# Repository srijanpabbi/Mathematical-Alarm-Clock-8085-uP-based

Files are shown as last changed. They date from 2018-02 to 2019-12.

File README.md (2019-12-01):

# Mathematical-Alarm-Clock
#[Find PDF in git repo(Brief Document)]
This device aims to make turning off an alarm a slightly more involving task, forcing the user to focus on the device for some time hence breaking the sleep. It will keep track of time using a RTC and will sound an alarm on the preset time and throw a randomly generated integer based mathematical problem at the user(+,-,/,*), the alarm will stop ringing as soon as the user enters the correct answer to the question. This projects will incorporate a display, a keypad, alarm sounding system(buzzer), and a RTC.

## NETAJI SUBHAS INSTITUTE OFTECHNOLOGY

## DIVISION OFELECTRONICS AND COMMUNICATIONENGINEERING

### EC316 MICROPROCESSORLABPROJECTREPORT

# Mathematical Alarm Clock

## ANINTEL8085 MICROPROCESSOR BASED PROJECT

### Submitted by

### Prabhat Gupta (124EC15)

### Srijan Pabbi (173EC15)

### Submitted to

### Prof. Dhananjay V. Gadre

### May, 2018

## Contents

- 1 Abstract
- 2 Background And Motivation
- 3 Justification
- 4 Block Diagram
- 5 Technical Details
   - 5.1 Hardware
      - 5.1.1 Core Microprocessor (Intel 80C85)
      - 5.1.2 Peripherals And Addressing
      - 5.1.3 RTC(Real Time Clock)
      - 5.1.4 20x4 Character LCD
      - 5.1.5 Key-Pad
      - 5.1.6 Buzzer
   - 5.2 Software Implementation and Interesting Concepts
      - 5.2.1 Big Font and LCD Posting Techniques
      - 5.2.2 Key-Pad Scanning
      - 5.2.3 LFSR(Linear Feedback Shift Register) Implementation
      - 5.2.4 User Setup Inputs With Interrupts
      - 5.2.5 Arithmetic Random Problem Generation With Result Check
- 6 Supporting Materials
   - 6.1 Support Links and References
   - 6.2 Project Schematic And Boards
   - 6.3 Bill of Materials

## 1 Abstract

Everyone must have seen the ordinary alarm clocks that sound only when it is set to be alarmed.Why not
to make a normal alarm period an interesting task. It’s time to get rid of the conventional alarm clocks.
Here what comes the mathematical alarm clock. The mathematical alarm clock is a device that modifies
a conventional alarm clock to a more advanced version that not only alarms but it also makes sure that
the user gets out of sleep for solving some mathematical problems.This device aims to make turning on an
alarm a slightly more involving task. It keeps the trackof time and displays it on the lcd. It does so by using
an RTC (parallel data bus). The Alarm can be set using a keypad. At the time of alarm, a buzzer sounds. The
buzzing of the alarm continues as long as the user would not give the correct answers of certain number of
mathematical problems. At the alarm preset time, the device throws a randomly generated integer based
mathematical problem based on simple arithmetic (+). The alarm stops only after the correct answer is
given by the user. The project incorporates a display (LCD 20x4),keypad, buzzer as an alarming system,
parallel bus RTC

## 2 Background And Motivation

EC-311/316 has provided us an opportunity to build this project under the able guidance of Prof Dhanan-
jay Gadre. The idea of this project is to learn and portray the skill of designing a microprocessor based
system and putting whatever we learn in this course into a useful application. This device aims to make
turning on an alarm a slightly more involving task, forcing the user to focus on the device for some time
hence successfully breaking the sleep as compared to normal alarm clocks. Making this project will involve
almost all the steps required for making a embedded system product namely; planning, designing, getting
the pcb fabricated, coding, and a making an enclosure for the final display, and most importantly docu-
menting throughout the process of making it, which will give us experience on how to design a embedded
product from zero to finish.

## 3 Justification

Mathematical Alarm Clock involves the use of a RTC(Real Time Clock) for time keeping, 20x4 character
LCD for display of time and the generated math questions, and a user input keypad, these devices cannot
be used with simple digital logic devices to perform the job we want out of this project. This project must
be able to display time and, perform background mathematical calculations , accept and compare user
inputs to the answers of the questions which it generated randomly. The need to do all this for successful
working of the project the use of a microprocessor which is fairly fast and can perform slightly complex
mathematical calculations is justified.

## 4 Block Diagram

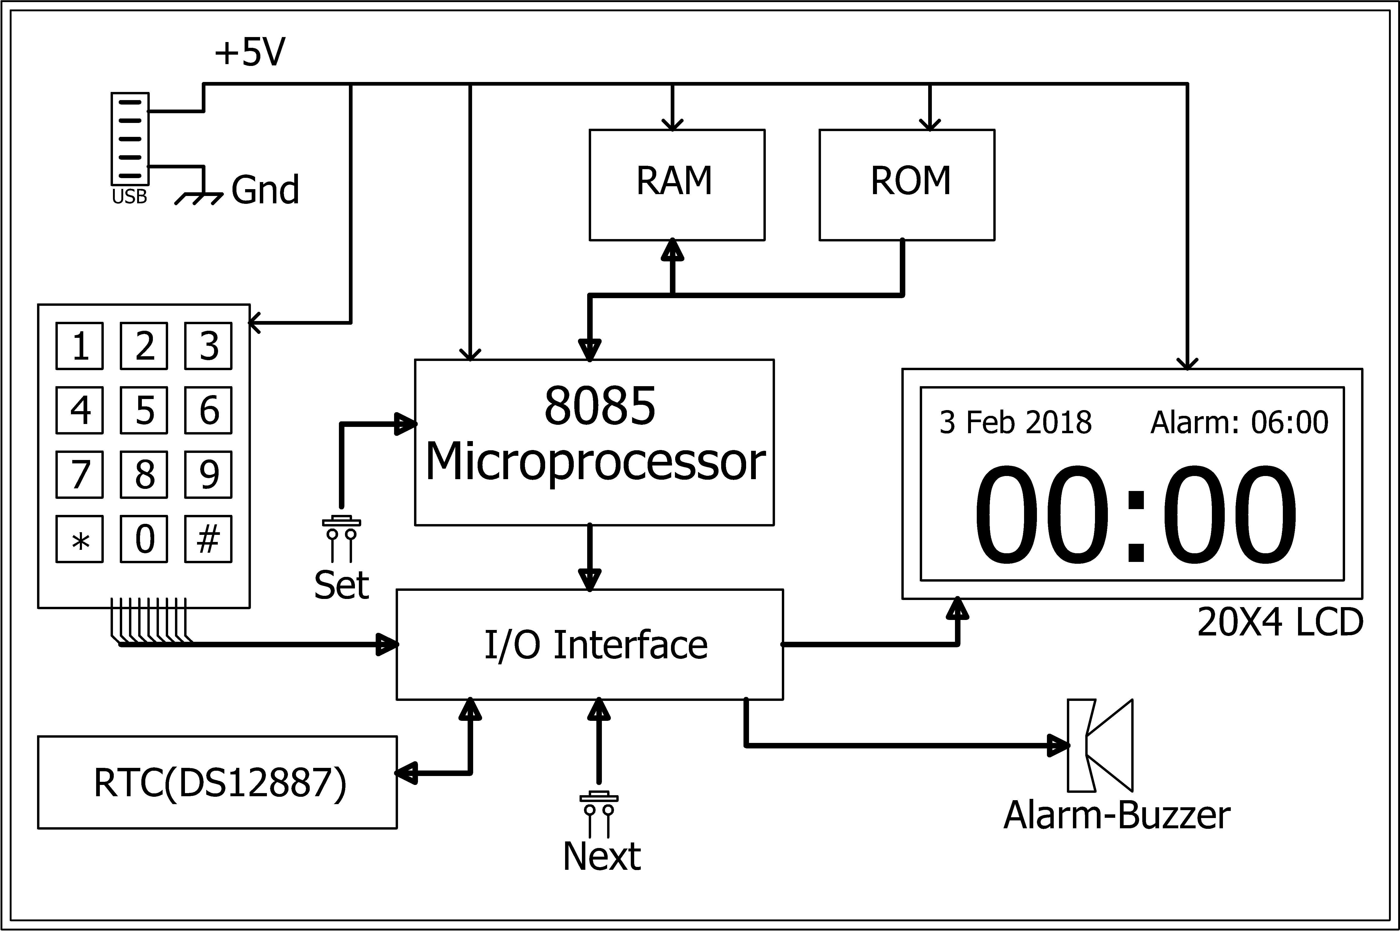
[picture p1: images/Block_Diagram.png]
Figure 1: Block Diagram of Mathematical Alarm Clock

```
Figure 1: Block Diagram of Mathematical Alarm Clock
```

## 5 Technical Details

##### „„„„„„„„„„„„„„„„„„„„„„„„„„„„

### 5.1 Hardware

#### 5.1.1 Core Microprocessor (Intel 80C85)

At the heart of this project is an Intel 80C85 microprocessor( _μ_ P) from OKI Semiconductors is a CMOS im-
plementation of the original TTL 8085 which has a quiescent current of as low as 10mA. The microprocessor
has a 64KB memory address space and 256 bytes of I/O space. In this case the 8085 is running at 3MHz
from the clock of a 6MHz crystal oscillator.

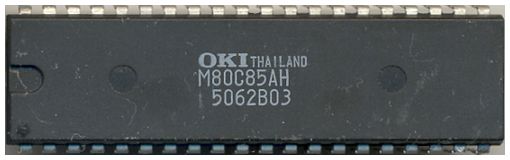
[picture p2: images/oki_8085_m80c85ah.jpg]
Figure 2: OKI 8085

```
Figure 2: OKI 8085
```

#### 5.1.2 Peripherals And Addressing

This project employs a Atmel ROM 28C256, Intel 8155 PPI+RAM+Timer, Maxim DS12887 RTC, as periph-
erals for the microprocessor and hence they occupy some part of the 8085’s address space.

- Atmel ROM 28C256: Is a 32KB rom which is over kill for this project but was chosen due to its ready
    availability and most of the address space of the 8085 microprocessor is not in use.
    -The address space for the ROM ranges from 0000hto 0FFFh.
    -Chip Select(CS) for this IC is connected toA 15 of the _μ_ P
- Intel 8155: Is a IC specially developed to be used with the Intel 8085 _μ_ P. It has 256bytes of RAM, 3
    I/O ports 2 of 8bit and 1 of 6bit, with handshake capability using the former as I/O and the latter for
    handshaking, and a 8 bit timer with clock out.
    -The address space for the RAM ranges from 8000hto 80FFh.
    -The IO addresses for 8155CWR-00h, PORTA-01h, PORTB-02h, PORTC-03h
    -Chip Select(CS) for this IC is connected toA 15 of the _μ_ P
- RTC: This IC is a complete package of an RTC, battery, and crystal, along with a non-volatile RAM in
    the RTC. This chip implements the Intel Bus Protocol Internally and hence can be memory mapped.
    -The address space for the RTC ranges from 8100hto 8180h.
    -Chip Select(CS) for this IC is connected via a decoding logic as shown in Figure 7

#### 5.1.3 RTC(Real Time Clock)

The real time clock employed for this project DS12887A from Maxim Integrated is a parallel bus RTC with
data exchange via the Intel bus protocol implemented internally. This RTC comes in a 24 pin EDIP package
with internally implemented crystal oscillator and a battery. It can count time on both binary as well as
BCD format with one-time of the day alarm, and an added feature of daylight saving by keeping track
of the exact day,date,year,and century of the millennium. Alongside the basic time keeping features, it
can interrupt the processor about an alarm situation. It can also produce a square wave out of various
frequencies which can be used to drive an alarm sounding system.
The following is the schematic implementation of the RTC.

#### 5.1.4 20x4 Character LCD

The display used in our project is 20X4 LCD display. It is said so as it has 4 rows with 20 characters each.
It uses HD44780 driver. The customized characters are generated using CGRAM. 7 special characters are
stored at seven locations of CGRAM. Using these seven characters any of the character or digit can be
produced. Its contrast and brightness are controlled using two independent presets.

#### 5.1.5 Key-Pad

The keypad used is 4X3 that means it has 4 rows and 3 columns. The switches that are used in the keypad
matrix is 40XX tactile switches. It is interfaced using polling technique. In the polling technique, each
switch press is detected by polling individual switches. In this, rows are treated as input and columns as
output. A switch is identified by outputting through columns and inputting through rows.

#### 5.1.6 Buzzer

The buzzer used here is the D.C. buzzer. It is derived through a port pin of 8155 using a transistor as a
switch.

### 5.2 Software Implementation and Interesting Concepts

#### 5.2.1 Big Font and LCD Posting Techniques

Big Font or customized characters are generated using the CGRAM of the lcd. For generating these char-
acters, some special patterns(7) are stored in the CGRAM. Using these seven patterns, by appropriate
positioning, any big character can be generated.

```
(a) Decimal Digits In Bigfont
```

```
(b) Building Blocks For The Digits
```

```
In order to initialize the LCD the following set of commands need to be sent on the LCD port using
the command function explained later. The first command is used to set the LCD into the 8 bit
data acceptance mode along with a 2 line spill over, which means that if the first line is filled with
characters, the next character sent will be automatically printed in the next line. The second command
clears the LCD of any previous garbage value. Next comes the display on command and the cursor
mode determination. At the end the entry mode is specifier which determines the movement of data
or the cursor on the data input to the LCD.

1 LCD_INIT : MVI C, 38h ; 8 bit 2 line mode
2 CALL SEND_CMD
3 MVI C, 0 1 h          ; clear lcd
4 CALL SEND_CMD
5 MVI C , 0 Ch          ; display on, cursoroff, blinkoff
6 CALL SEND_CMD
7 MVI C, 0 6 h          ; entry mode
8 CALL SEND_CMD
9 RET
```

- The following are two subroutines which are used to send either data or commands to the LCD
    display. Both of them follow a strict protocol in which first the data or command word is made
    available on the PORTB lines of the 8155. The protocol next requires the LCDRS to be either high or
    low depending on the type of word, data or command. Next a pulse of LCDEN is required for the
    LCD controller to take in the data after which a delay is given to perform the operation successfully
    without any interference.
1 SEND_DATA : PUSH PSW ; C f o r a r g
2 MOV A, C ;DATA OUT
3 OUT PORTB
4 IN PORTA

5 ORI LCDRS ; f o r making r s 1
6 OUT PORTA ; s e n d i n g r s b e f o r e l c d _ e n
7 ORI LCDEN ; EN p u l s e
8 OUT PORTA
9 ANI 0FBh
10 OUT PORTA
11 CALL DELAY_2MS
12 POP PSW
13 RET
14
15 SEND_CMD : PUSH PSW ; C f o r a r g
16 MOV A, C ;COMMAND OUT
17 OUT PORTB
18 IN PORTA
19 ANI 0FDh ; f o r making r s 0
20 OUT PORTA ; s e n d i n g r s b e f o r e l c d _ e n
21 ORI LCDEN ; EN p u l s e
22 OUT PORTA
23 ANI 0FBh
24 OUT PORTA
25 CALL DELAY_2MS
26 POP PSW
27 RET
28

#### 5.2.2 Key-Pad Scanning

```
Figure 4: Connections To port A and C
```
```
It is interfaced using polling technique. In the polling tech-
nique, each switch press is detected by polling individual
switches. In this, rows are treated as input and columns
as output. A switch is identified by outputting through
columns and inputting through rows.
```
1
2 KEYPAD : PUSH PSW
3 PUSH H
4 COL1 : IN PORTA ; i n p u t c u r r e n t s t a t e o f portA
5 ANI 0 F7h ; make t h e K_5 b i t a s 0 t o r e a d i n p u t s f o r c o l 1 o n l y
6 OUT PORTA
7 CALL DELAY_2MS ; debouncing d e l a y
8 IN PORTC ; r e a d t h e column
9 ANI 0Fh
10 PRES1 : CPI 0Eh ; i s b u t t o n i n row 1 p r e s s e d?
11 JNZ PRES
12 MVI A, 0 1 h
13 JMP ENDKEYPAD
14 PRES4 : CPI 0Dh ; i s b u t t o n i n row 2 p r e s s e d?
15 JNZ PRES
16 MVI A, 0 4 h
17 JMP ENDKEYPAD
18 PRES7 : CPI 0Bh ; i s b u t t o n i n row 3 p r e s s e d?
19 JNZ PRESS
20 MVI A, 0 7 h
21 JMP ENDKEYPAD
22 PRESS10 : CPI 07 h ; i s b u t t o n i n row 4 p r e s s e d?
23 JNZ COL
24 MVI A, 0 Ah
25 JMP ENDKEYPAD
26
27 COL2 :...
28
29 COL3 :...
30
31 ENDKEYPAD :
32 CPI 0Fh ; i s no b u t t o n p r e s s e d?
33 JZ COL1 ; i f t h a t i s t h e c a s e t h e n c o n t i n u e p o l l i n g
34 LXI H, PRESSED
35 MOV M, A ; s t o r e t h e p r e s s e d
36 CALL DELAY_500MS
37 IN PORTA
38 ORI 38 h make t h e K_5 , 6 , 7 i n a c t i v e
39 OUT PORTA
40 POP H
41 POP PSW
42 RET
43

Figure 5: Keypad Scanning Algorithm Flowchart

#### 5.2.3 LFSR(Linear Feedback Shift Register) Implementation

```
Figure 6: Flowchart of LFSR Algorithm
```
```
It is an algorithm to generate random numbers. In this
method we have two components- seed and mask. Algo-
rithm goes this way: seed value is masked using mask value
such that the bits in seed, corresponding to the ones in mask
value, are XORed and the resultant is moved to the MSB of
seed and the other bits are shifted one to left. In this way we
generate a random number each time this cycle is repeated.
1 LFSR : PUSH PSW ; RET VAL IN THE SEED LOC
2 PUSH B
3 PUSH D
4 PUSH H
5 LXI H, SEED
6 MOV A,M ; r e t r i e v e s e e d
7 LXI H, BITS
8 ANA M ; r e t r i e v e mask b i t s
9 MVI B , 0 0H ; c o u n t
10 MVI C, 0 8H ; 8 b i t s
11 LOOP1 : RRC ; LSB i n CARRY
12 JNC NXT
13 INR B ; i n c r e m e n t B i s c a r r y i s 1
14 NXT1 : DCR C
15 JNZ LOOP
16 MOV A, B
17 RLC
18 RLC
19 RLC
20 RLC
21 RLC
22 RLC
23 RLC
24 ANI 80H
25 MOV B , A ; s t o r e t h e XOR r e s u l t
26 ; i n t h e MSB o f B
27 LXI H, SEED
28 MOV A,M
29 STC
30 CMC
31 RAR ; r o t a t e SEED making MSB=
32 ORA B ; put t h e new MSB v a l from B
33 STA SEED ; r e p l a c e o l d s e e d
34 ; v a l with new rand no.
35 POP H
36 POP D
37 POP B
38 POP PSW
39 RET
```

#### 5.2.4 User Setup Inputs With Interrupts

Interrupt RST7.5 is used as an user interface to update the timings of normal day time and the alarm time.
It’s a user interacting switch which is connected to RST7.5. Each time this switch is pressed, program
transfers to settings window to set either day time or alarm time. According to the option selected, settings
transfer to set the required time.

#### 5.2.5 Arithmetic Random Problem Generation With Result Check

Each time alarm time matches the regular time, program transfers to a section in which some random
problems(based on addition) are generated using LFSR algorithm. The result to these problems are also
calculated and stored n the memory at the same time. The results are checked against the ones that are
inputted by the user. Only when the result matches the input the alarm goes off otherwise more random
problems are generated.

## 6 Supporting Materials

##### „„„„„„„„„„„„„„„„„„„„„„„„„„„„

### 6.1 Support Links and References

- Youtube Video: https://www.youtube.com/watch?v=FnkgJ6MPxQ
- GITHUB Link for Code: https://github.com/srijanpabbi/Mathematical-Alarm-Clock-8085-uP-based
- Programmer and Assembler related Material: https://drive.google.com/drive/folders/0B3dkOo5f1Sb-
    ZHQ5bHRYb3ZnR2c?usp=sharing
- Other 8085 Projects for Reference: [http://www.8085projects.in/](http://www.8085projects.in/)
- A forum discussion on LCD bigfont: https://www.avrfreaks.net/forum/alphanumeric-lcd-hd44780-
    big-font-big-digits-generator-excel-sheet
- Full End to End character LCD tutorial in C as well as Assembly Language
- RTC Datasheet: https://pdfserv.maximintegrated.com/en/ds/DS12885-DS12C887A.pdf
- OKI 80C85 Datasheet: [http://elearning.tukenya.ac.ke/course/view.php?id=](http://elearning.tukenya.ac.ke/course/view.php?id=)
- LCD Controller Datasheet: https://www.sparkfun.com/datasheets/LCD/HD44780.pdf

### 6.2 Project Schematic And Boards

```
Figure 7: Logic Board Schematic
```

```
Figure 8: Logic Board Layout
```
Figure 9: User Interface Board Schematic

```
Figure 10: User Interface Board Layout
```
### 6.3 Bill of Materials

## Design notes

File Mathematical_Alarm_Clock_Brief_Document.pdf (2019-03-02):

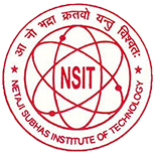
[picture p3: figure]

### NETAJI SUBHAS INSTITUTE OF TECHNOLOGY

DIVISION OF ELECTRONICS AND COMMUNICATION ENGINEERING

EC316 MICROPROCESSOR LAB PROJECT REPORT

# Mathematical Alarm Clock

AN INTEL 8085 MICROPROCESSOR BASED PROJECT

Submitted by
Prabhat Gupta (124EC15)
Srijan Pabbi (173EC15)

Submitted to
Prof. Dhananjay V. Gadre

May, 2018

### Contents

1 Abstract | 3
2 Background And Motivation | 4
3 Justification | 4
4 Block Diagram | 5
5 Technical Details | 6
6 Supporting Materials | 14

### 1 Abstract

Everyone must have seen the ordinary alarm clocks that sound only when it is set to be alarmed.Why not to make a normal alarm period an interesting task. It’s time to get rid of the conventional alarm clocks. Here what comes the mathematical alarm clock. The mathematical alarm clock is a device that modifies a conventional alarm clock to a more advanced version that not only alarms but it also makes sure that the user gets out of sleep for solving some mathematical problems.This device aims to make turning on an alarm a slightly more involving task. It keeps the trackof time and displays it on the lcd. It does so by using an RTC (parallel data bus). The Alarm can be set using a keypad. At the time of alarm, a buzzer sounds. The buzzing of the alarm continues as long as the user would not give the correct answers of certain number of mathematical problems. At the alarm preset time, the device throws a randomly generated integer based mathematical problem based on simple arithmetic (+). The alarm stops only after the correct answer is given by the user. The project incorporates a display (LCD 20x4),keypad, buzzer as an alarming system, parallel bus RTC

### 2 Background And Motivation

EC-311/316 has provided us an opportunity to build this project under the able guidance of Prof Dhananjay Gadre. The idea of this project is to learn and portray the skill of designing a microprocessor based system and putting whatever we learn in this course into a useful application. This device aims to make turning on an alarm a slightly more involving task, forcing the user to focus on the device for some time hence successfully breaking the sleep as compared to normal alarm clocks. Making this project will involve almost all the steps required for making a embedded system product namely; planning, designing, getting the pcb fabricated, coding, and a making an enclosure for the final display, and most importantly documenting throughout the process of making it, which will give us experience on how to design a embedded product from zero to finish.

### 3 Justification

Mathematical Alarm Clock involves the use of a RTC(Real Time Clock) for time keeping, 20x4 character LCD for display of time and the generated math questions, and a user input keypad, these devices cannot be used with simple digital logic devices to perform the job we want out of this project. This project must be able to display time and, perform background mathematical calculations , accept and compare user inputs to the answers of the questions which it generated randomly. The need to do all this for successful working of the project the use of a microprocessor which is fairly fast and can perform slightly complex mathematical calculations is justified.

### 4 Block Diagram

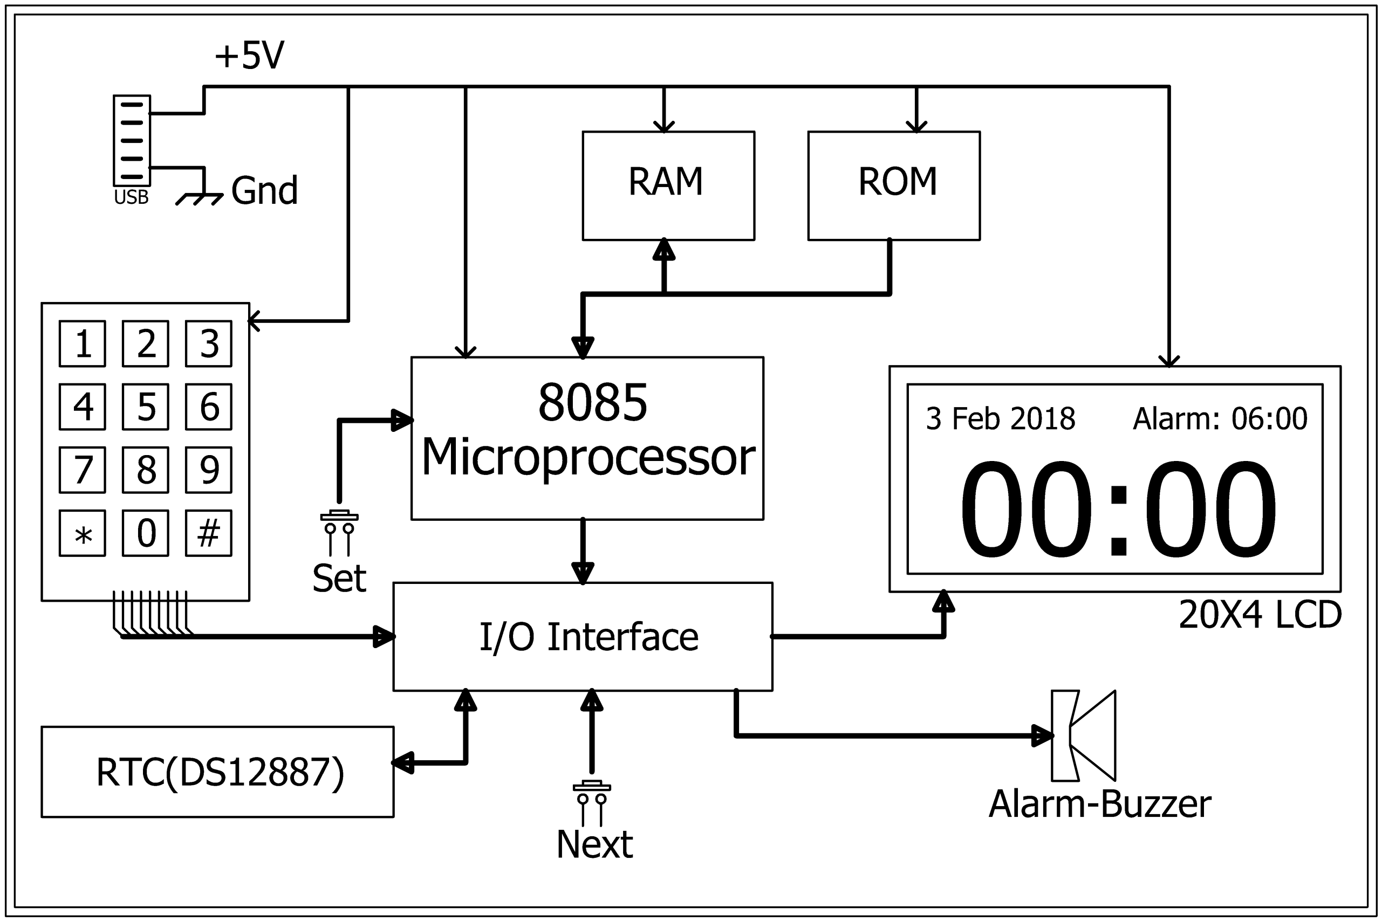
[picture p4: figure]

Figure 1: Block Diagram of Mathematical Alarm Clock

### 5 Technical Details

„„„„„„„„„„„„„„„„„„„„„„„„„„„„

### 5.1 Hardware

### 5.1.1 Core Microprocessor (Intel 80C85)

At the heart of this project is an Intel 80C85 microprocessor(µP) from OKI Semiconductors is a CMOS implementation of the original TTL 8085 which has a quiescent current of as low as 10mA. The microprocessor has a 64KB memory address space and 256 bytes of I/O space. In this case the 8085 is running at 3MHz from the clock of a 6MHz crystal oscillator.

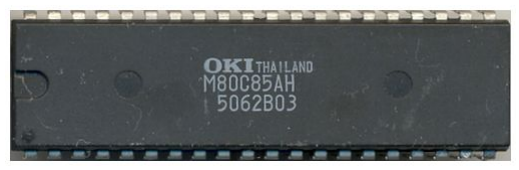
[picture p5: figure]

Figure 2: OKI 8085

### 5.1.2 Peripherals And Addressing

This project employs a Atmel ROM 28C256, Intel 8155 PPI+RAM+Timer, Maxim DS12887 RTC, as peripherals for the microprocessor and hence they occupy some part of the 8085’s address space.

- Atmel ROM 28C256: Is a 32KB rom which is over kill for this project but was chosen due to its ready availability and most of the address space of the 8085 microprocessor is not in use.
-The address space for the ROM ranges from 0000h to 0FFFh.
-Chip Select(CS) for this IC is connected to A15 of the µP
- Intel 8155: Is a IC specially developed to be used with the Intel 8085 µP. It has 256bytes of RAM, 3 I/O ports 2 of 8bit and 1 of 6bit, with handshake capability using the former as I/O and the latter for handshaking, and a 8 bit timer with clock out.
-The address space for the RAM ranges from 8000h to 80FFh.
-The IO addresses for 8155CWR-00h, PORTA-01h, PORTB-02h, PORTC-03h
-Chip Select(CS) for this IC is connected to A15 of the µP
- RTC: This IC is a complete package of an RTC, battery, and crystal, along with a non-volatile RAM in the RTC. This chip implements the Intel Bus Protocol Internally and hence can be memory mapped. -The address space for the RTC ranges from 8100h to 8180h.
-Chip Select(CS) for this IC is connected via a decoding logic as shown in Figure 7

### 5.1.3 RTC(Real Time Clock)

The real time clock employed for this project DS12887A from Maxim Integrated is a parallel bus RTC with data exchange via the Intel bus protocol implemented internally. This RTC comes in a 24 pin EDIP package with internally implemented crystal oscillator and a battery. It can count time on both binary as well as BCD format with one-time of the day alarm, and an added feature of daylight saving by keeping track of the exact day,date,year,and century of the millennium. Alongside the basic time keeping features, it can interrupt the processor about an alarm situation. It can also produce a square wave out of various frequencies which can be used to drive an alarm sounding system.
The following is the schematic implementation of the RTC.

5.1.4 20x4 Character LCD

The display used in our project is 20X4 LCD display. It is said so as it has 4 rows with 20 characters each. It uses HD44780 driver. The customized characters are generated using CGRAM. 7 special characters are stored at seven locations of CGRAM. Using these seven characters any of the character or digit can be produced. Its contrast and brightness are controlled using two independent presets.

### 5.1.5 Key-Pad

The keypad used is 4X3 that means it has 4 rows and 3 columns. The switches that are used in the keypad matrix is 40XX tactile switches. It is interfaced using polling technique. In the polling technique, each switch press is detected by polling individual switches. In this, rows are treated as input and columns as output. A switch is identified by outputting through columns and inputting through rows.

### 5.1.6 Buzzer

The buzzer used here is the D.C. buzzer. It is derived through a port pin of 8155 using a transistor as a switch.

### 5.2 Software Implementation and Interesting Concepts

### 5.2.1 Big Font and LCD Posting Techniques

Big Font or customized characters are generated using the CGRAM of the lcd. For generating these characters, some special patterns(7) are stored in the CGRAM. Using these seven patterns, by appropriate positioning, any big character can be generated.

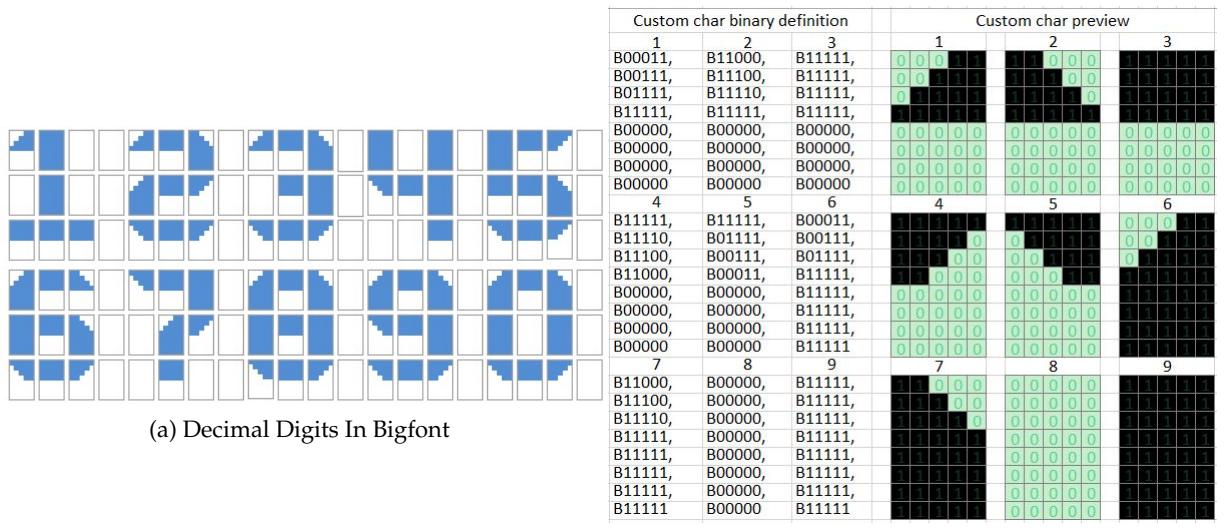
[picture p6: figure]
(a) Decimal Digits In Bigfont

(b) Building Blocks For The Digits
- In order to initialize the LCD the following set of commands need to be sent on the LCD port using the command function explained later. The first command is used to set the LCD into the 8 bit data acceptance mode along with a 2 line spill over, which means that if the first line is filled with characters, the next character sent will be automatically printed in the next line. The second command clears the LCD of any previous garbage value. Next comes the display on command and the cursor mode determination. At the end the entry mode is specifier which determines the movement of data or the cursor on the data input to the LCD.
1 | LCD_INIT : | MVI C, 3 8 h | ; 8 b i t 2 l i n e mode
2 | CALL SEND_CMD
3 | | MVI C, 0 1 h | ; c l e a r l cd
4 | CALL SEND_CMD
5 | | MVI C, 0 Ch | ; di spl a y on , cu r s o r o f f , bli n k o f f
6 | CALL SEND_CMD
7 | | MVI C, 0 6 h | ; en t ry mode
8 | CALL SEND_CMD
9 | | RET

10

- The following are two subroutines which are used to send either data or commands to the LCD display. Both of them follow a strict protocol in which first the data or command word is made available on the PORTB lines of the 8155. The protocol next requires the LCDRS to be either high or low depending on the type of word, data or command. Next a pulse of LCDEN is required for the LCD controller to take in the data after which a delay is given to perform the operation successfully without any interference.
1 | SEND_DATA: | PUSH PSW | ; C f o r arg
2 | | MOV A, C | ;DATA OUT
3 | | OUT PORTB
4 | | IN PORTA

5 | | ORI LCDRS | ; f o r making r s 1
6 | | OUT PORTA | ; sending r s be f o re lcd_en
7 | | ORI LCDEN | ;EN pulse
8 | | OUT PORTA
9 | | ANI 0FBh
10 | | OUT PORTA
11 | CALL DELAY_2MS
12 | | POP PSW
13 | | RET

14
15 | SEND_CMD: | PUSH PSW | ; C f o r arg
16 | | MOV A, C | ;COMMAND OUT
17 | | OUT PORTB
18 | | IN PORTA
19 | | ANI 0FDh | ; f o r making r s 0
20 | OUT PORTA ; sending r s be f o re lcd_en
21 | | ORI LCDEN | ;EN pulse
22 | | OUT PORTA
23 | | ANI 0FBh
24 | | OUT PORTA
25 | CALL DELAY_2MS
26 | | POP PSW
27 | | RET

28

### 5.2.2 Key-Pad Scanning

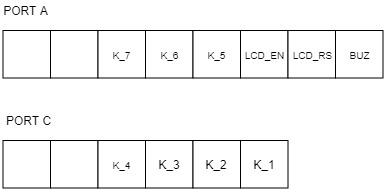
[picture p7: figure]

Figure 4: Connections To port A and C

It is interfaced using polling technique. In the polling technique, each switch press is detected by polling individual switches. In this, rows are treated as input and columns as output. A switch is identified by outputting through columns and inputting through rows.

1
2 | KEYPAD: PUSH PSW
3 | | PUSH H
4 | COL1 : | IN PORTA | ; inpu t c u r r e n t s t a t e o f portA
5 | | ANI 0F7h | ; make the K_5 b i t as 0 to read inpu t s f o r c ol 1 only
6 | | OUT PORTA
7 | CALL DELAY_2MS; debouncing delay
8 | | IN PORTC | ; read the column
9 | | ANI 0Fh
10 | PRES1 : | CPI 0Eh | ; i s bu t ton in row 1 p ressed ?
11 | | JNZ PRES4
12 | | MVI A, 0 1 h
13 | JMP ENDKEYPAD
14 | PRES4 : | CPI 0Dh | ; i s bu t ton in row 2 p ressed ?
15 | | JNZ PRES7
16 | | MVI A, 0 4 h
17 | JMP ENDKEYPAD
18 | PRES7 : | CPI 0Bh | ; i s bu t ton in row 3 p ressed ?
19 | | JNZ PRESS10
20 | | MVI A, 0 7 h
21 | JMP ENDKEYPAD
22 | PRESS10 : CPI 07h | ; i s bu t ton in row 4 p ressed ?
23 | | JNZ COL2
24 | | MVI A, 0Ah
25 | JMP ENDKEYPAD

26
27 COL2 : . . .

28
29 COL3 : . . .

30
31 | ENDKEYPAD:
32 | | CPI 0Fh | ; i s no bu t ton pressed ?
33 | | JZ COL1 | ; i f t h a t i s the c a se then con tinue p olli n g
34 | LXI H, PRESSED
35 | | MOV M,A | ; s t o r e the pressed
36 | CALL DELAY_500MS
37 | | IN PORTA
38 | | ORI 38h | make the K_5 , 6 , 7 i n a c t i v e
39 | | OUT PORTA
40 | | POP H
41 | | POP PSW
42 | | RET

43

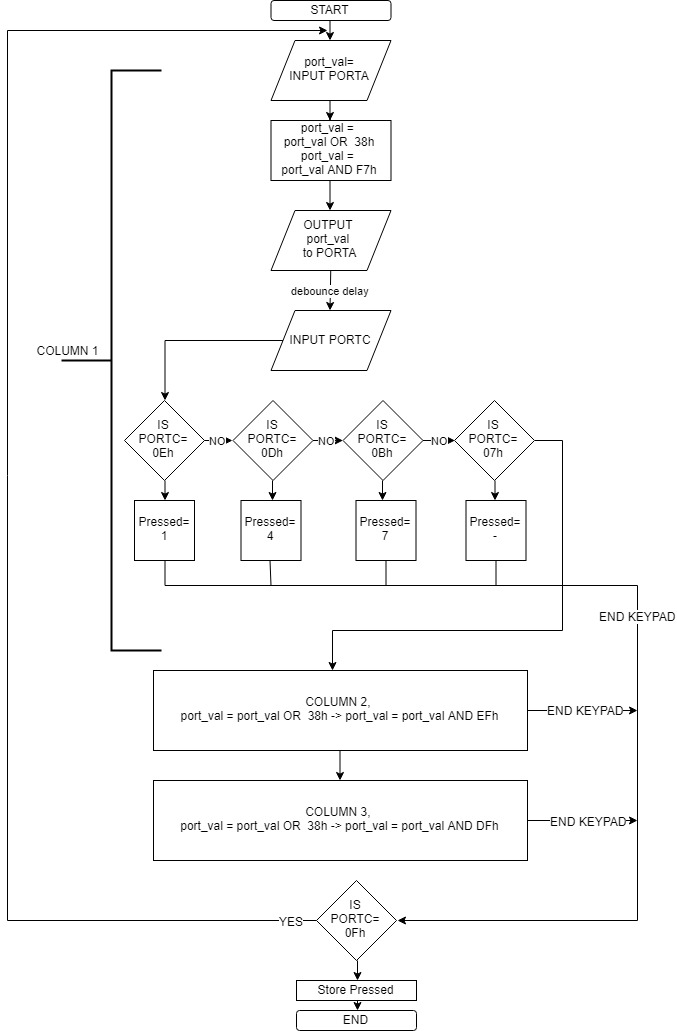
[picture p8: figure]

Figure 5: Keypad Scanning Algorithm Flowchart

### 5.2.3 LFSR(Linear Feedback Shift Register) Implementation

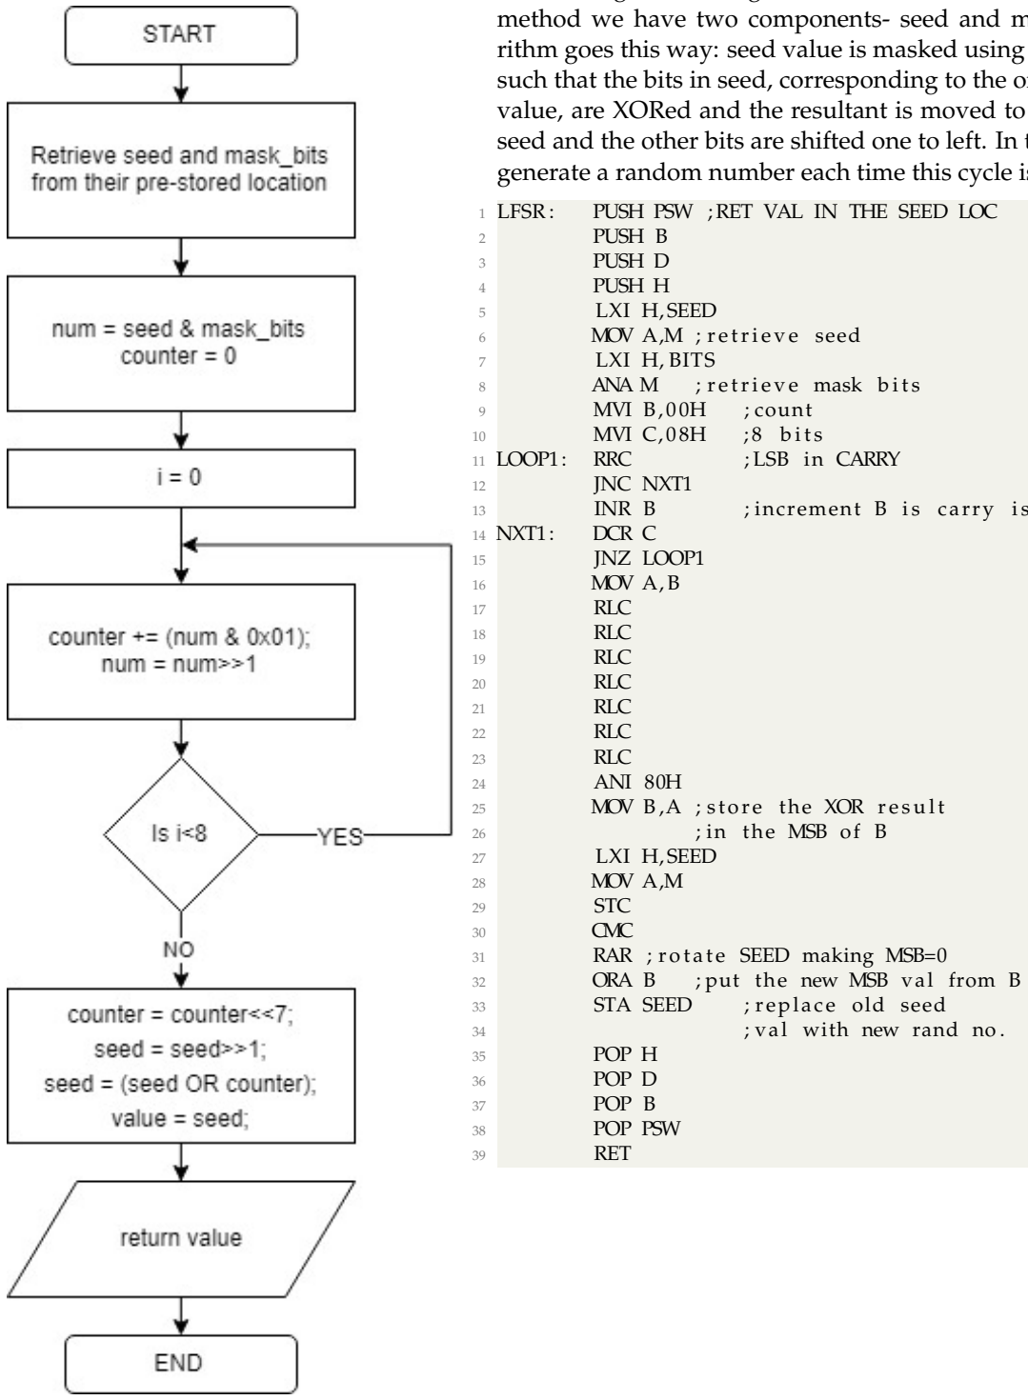
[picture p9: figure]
PUSH B; PUSH D; PUSH H; LXI H, SEED; MOV A,M ; r e t r i e v e seed; LXI H, BITS; ANA M; ; r e t r i e v e mask b i t s; MVI B , 0 0H; ; coun t; MVI C, 0 8H; LOOP1 :; RRC; ; LSB in CARRY; JNC NXT1; NXT1 :; DCR C; JNZ LOOP1; MOV A, B; RLC; ANI 80H; ; in the MSB o f B; MOV A,M; STC; CMC; RAR ; r o t a t e SEED making MSB=0; ORA B; ; put the new MSB v al from B; STA SEED; ; r e pl a c e old seed; ; v al with new rand no .; POP H; POP D; POP B; POP PSW; RET

Figure 6: Flowchart of LFSR Algorithm

It is an algorithm to generate random numbers. In this method we have two components- seed and mask. Algorithm goes this way: seed value is masked using mask value such that the bits in seed, corresponding to the ones in mask value, are XORed and the resultant is moved to the MSB of seed and the other bits are shifted one to left. In this way we generate a random number each time this cycle is repeated.

1 | LFSR : | PUSH PSW ; RET VAL IN THE SEED LOC
13 | INR B | ; incremen t B i s c a r r y i s 1
25 | MOV B ,A ; s t o r e the XOR r e s u l t

### 5.2.4 User Setup Inputs With Interrupts

Interrupt RST7.5 is used as an user interface to update the timings of normal day time and the alarm time. It’s a user interacting switch which is connected to RST7.5. Each time this switch is pressed, program transfers to settings window to set either day time or alarm time. According to the option selected, settings transfer to set the required time.

### 5.2.5 Arithmetic Random Problem Generation With Result Check

Each time alarm time matches the regular time, program transfers to a section in which some random problems(based on addition) are generated using LFSR algorithm. The result to these problems are also calculated and stored n the memory at the same time. The results are checked against the ones that are inputted by the user. Only when the result matches the input the alarm goes off otherwise more random problems are generated.

### 6 Supporting Materials

„„„„„„„„„„„„„„„„„„„„„„„„„„„„

### 6.1 Support Links and References

- Youtube Video: https://www.youtube.com/watch?v=FnkgJ6MPxQ0
- GITHUB Link for Code: https://github.com/srijanpabbi/Mathematical-Alarm-Clock-8085-uP-based
- Programmer and Assembler related Material: https://drive.google.com/drive/folders/0B3dkOo5f1Sb-ZHQ5bHRYb3ZnR2c?usp=sharing
- Other 8085 Projects for Reference: http://www.8085projects.in/
- A forum discussion on LCD bigfont: https://www.avrfreaks.net/forum/alphanumeric-lcd-hd44780-big-font-big-digits-generator-excel-sheet (https://www.avrfreaks.net/forum/alphanumeric-lcd-hd44780-big-font-big-digits-generator-excel-sheet)
- Full End to End character LCD tutorial in C as well as Assembly Language (https://www.8051projects.net/lcd-interfacing/introduction.php)
- RTC Datasheet: https://pdfserv.maximintegrated.com/en/ds/DS12885-DS12C887A.pdf
- OKI 80C85 Datasheet: http://elearning.tukenya.ac.ke/course/view.php?id=2424 (http://elearning.tukenya.ac.ke/pluginfile.php/14945/mod_resource/content/1/8085_datasheet-OKI.pdf)
- LCD Controller Datasheet: https://www.sparkfun.com/datasheets/LCD/HD44780.pdf

### 6.2 Project Schematic And Boards

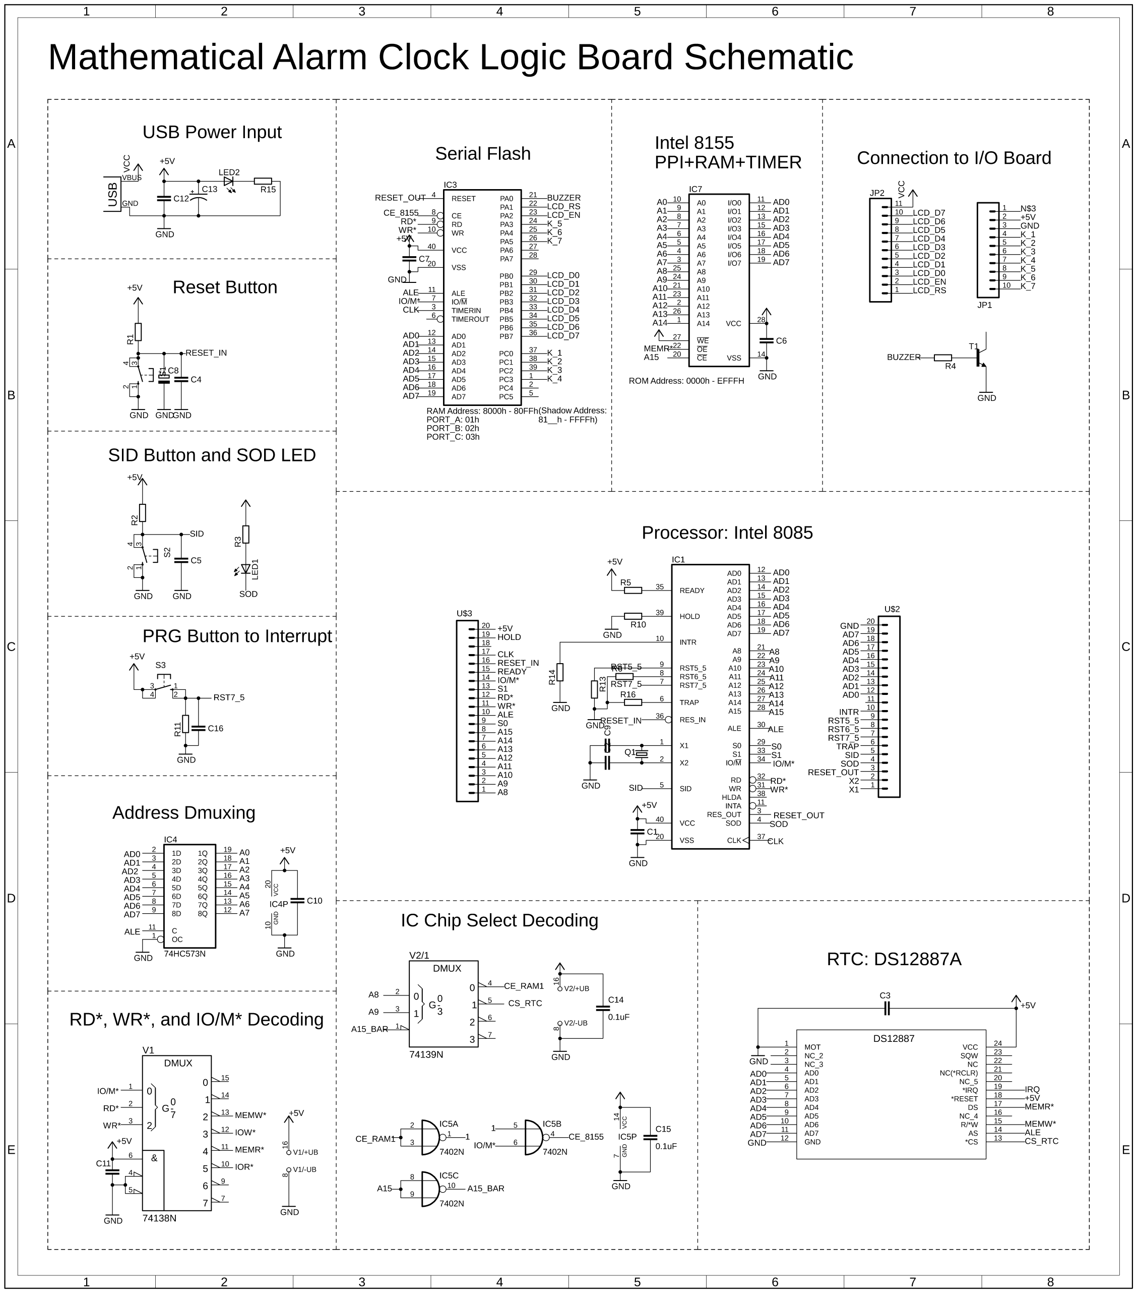
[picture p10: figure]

Figure 7: Logic Board Schematic

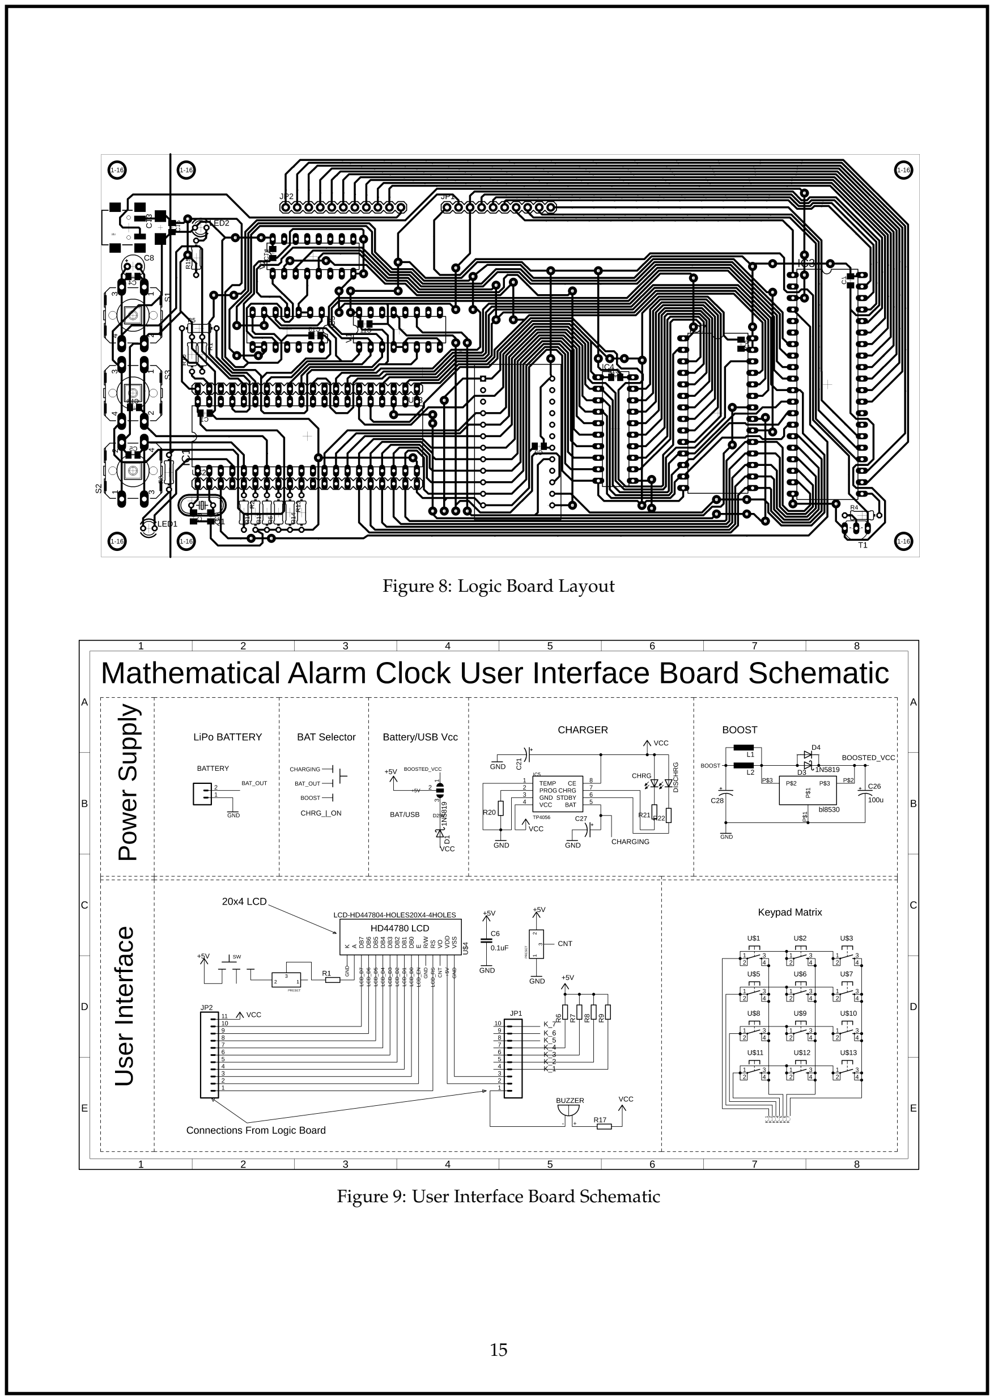
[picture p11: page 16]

Figure 8: Logic Board Layout

Figure 9: User Interface Board Schematic

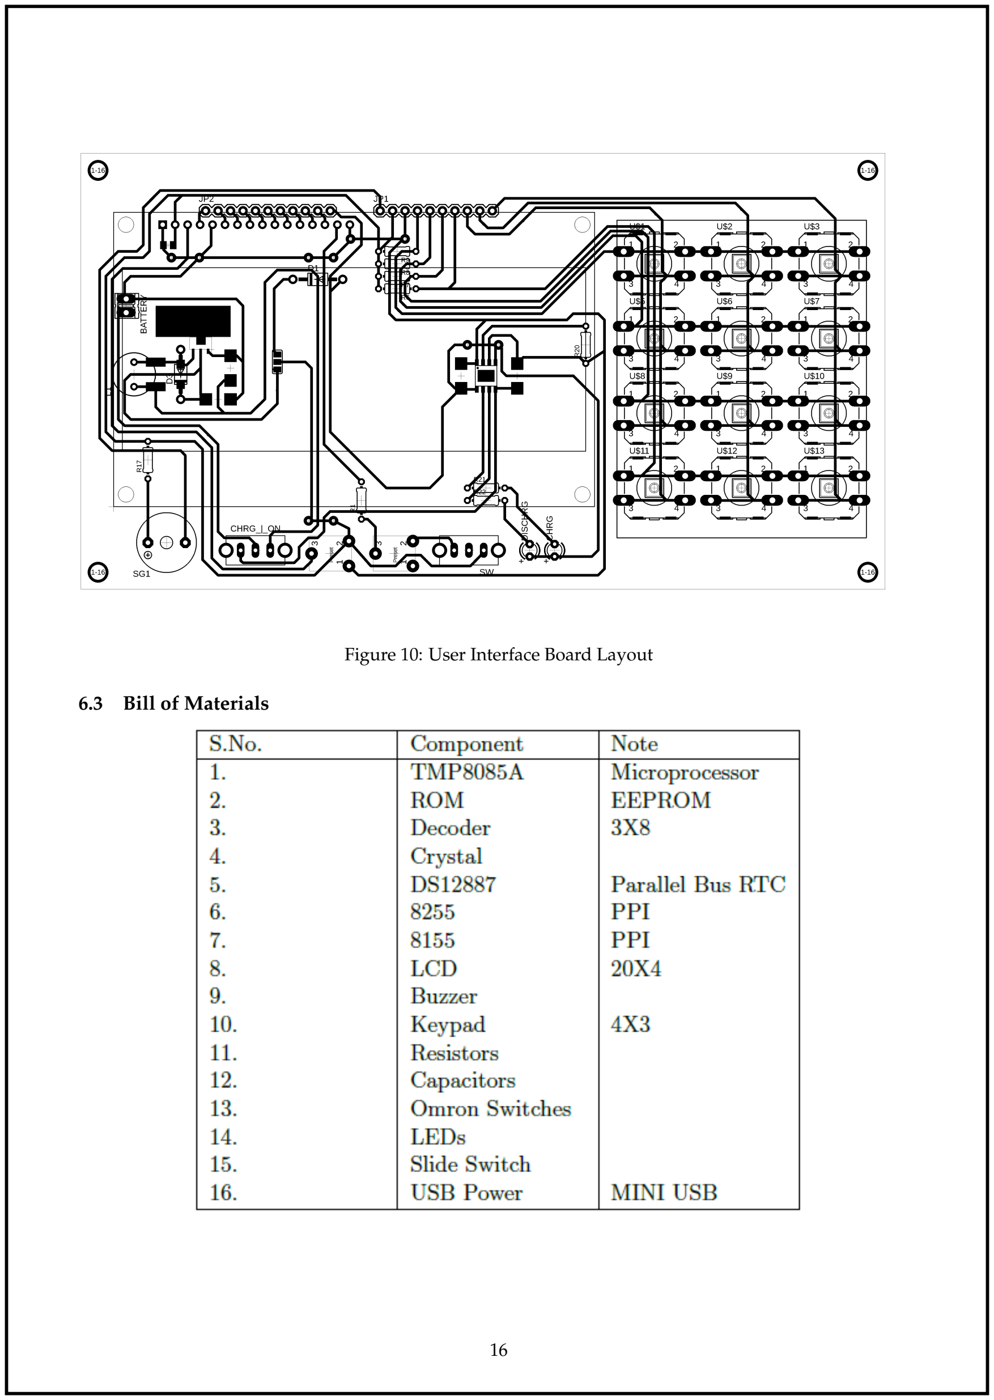
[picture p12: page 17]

Figure 10: User Interface Board Layout

### 6.3 Bill of Materials

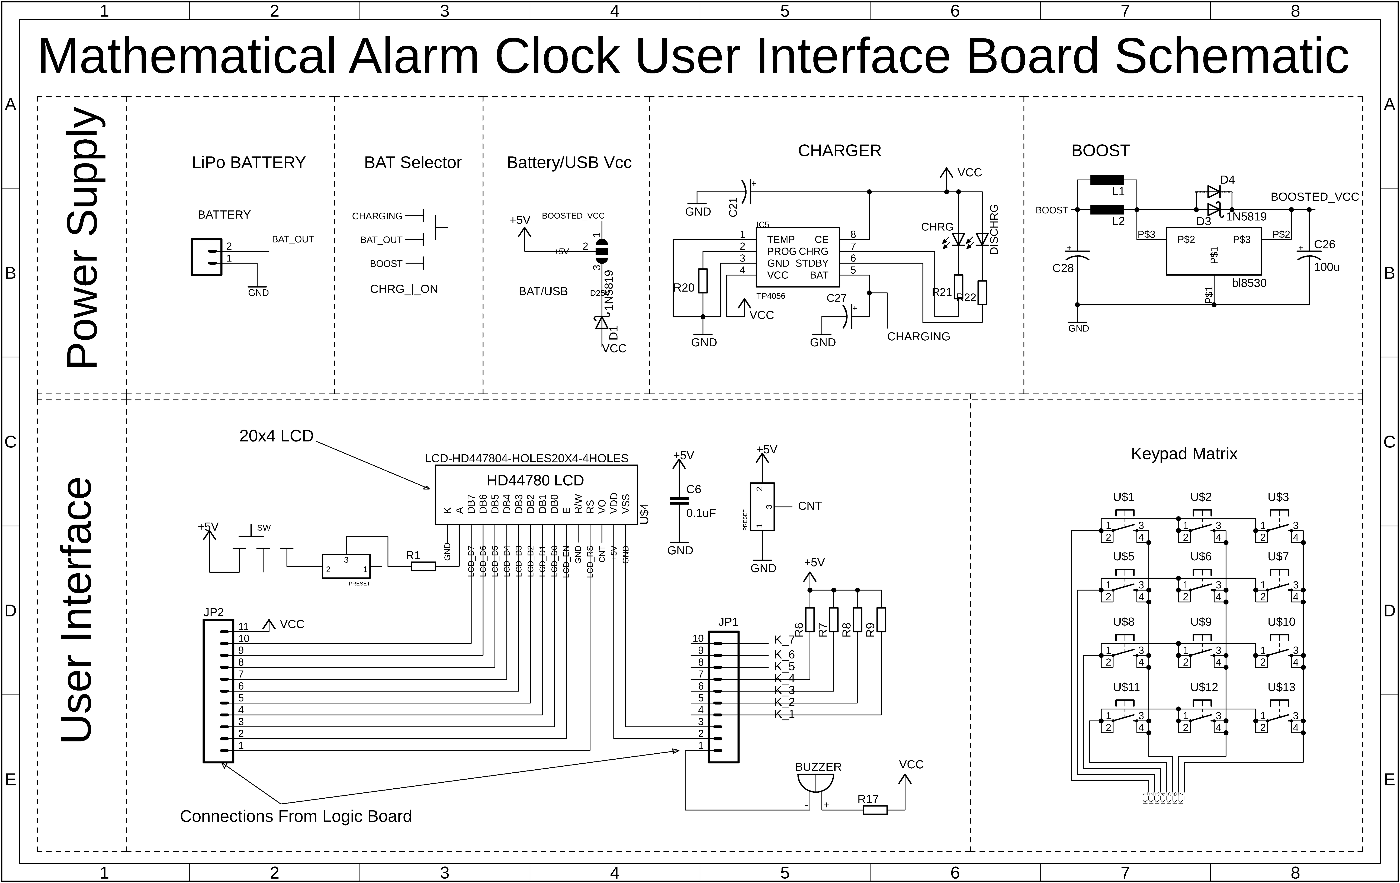
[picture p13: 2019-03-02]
images/uibrd.png

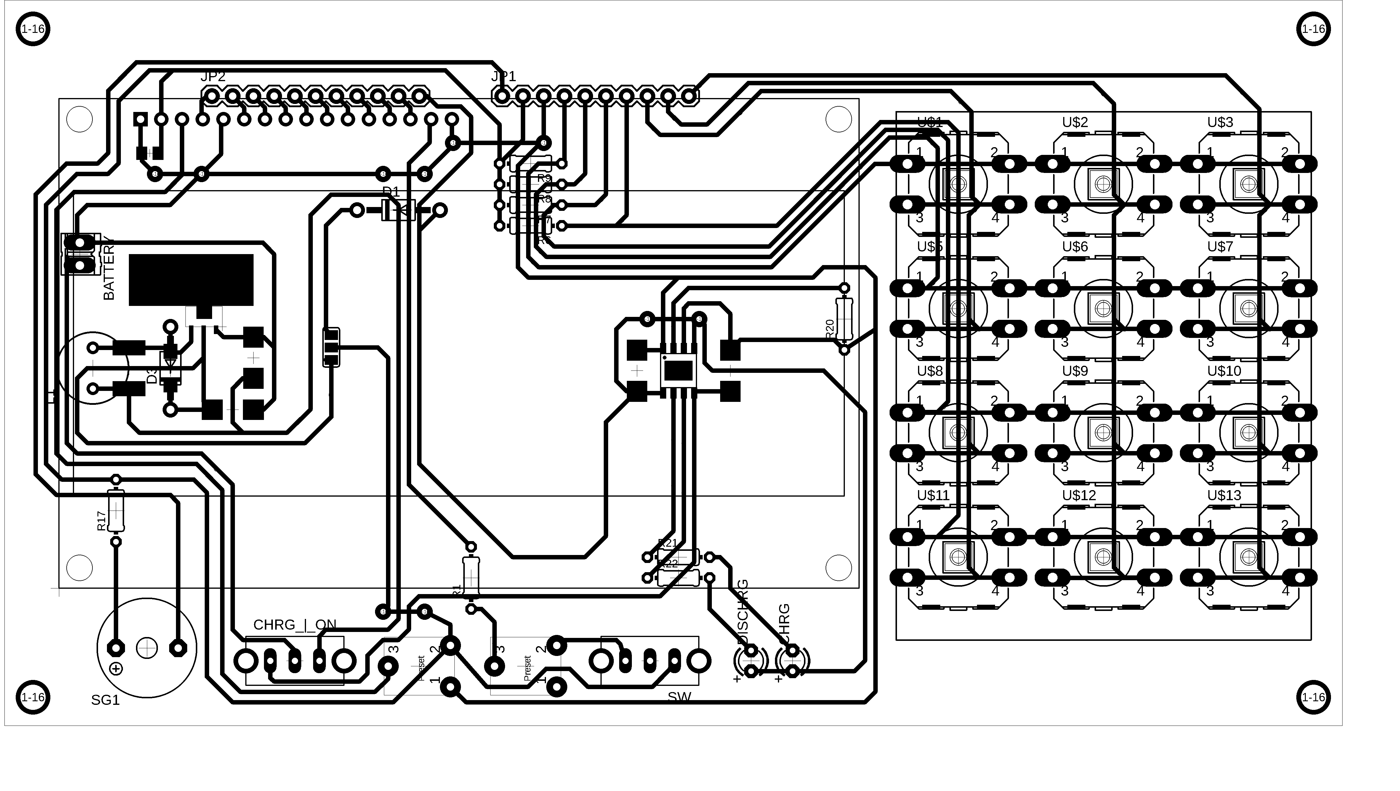
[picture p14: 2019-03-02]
images/uibrd(b).png

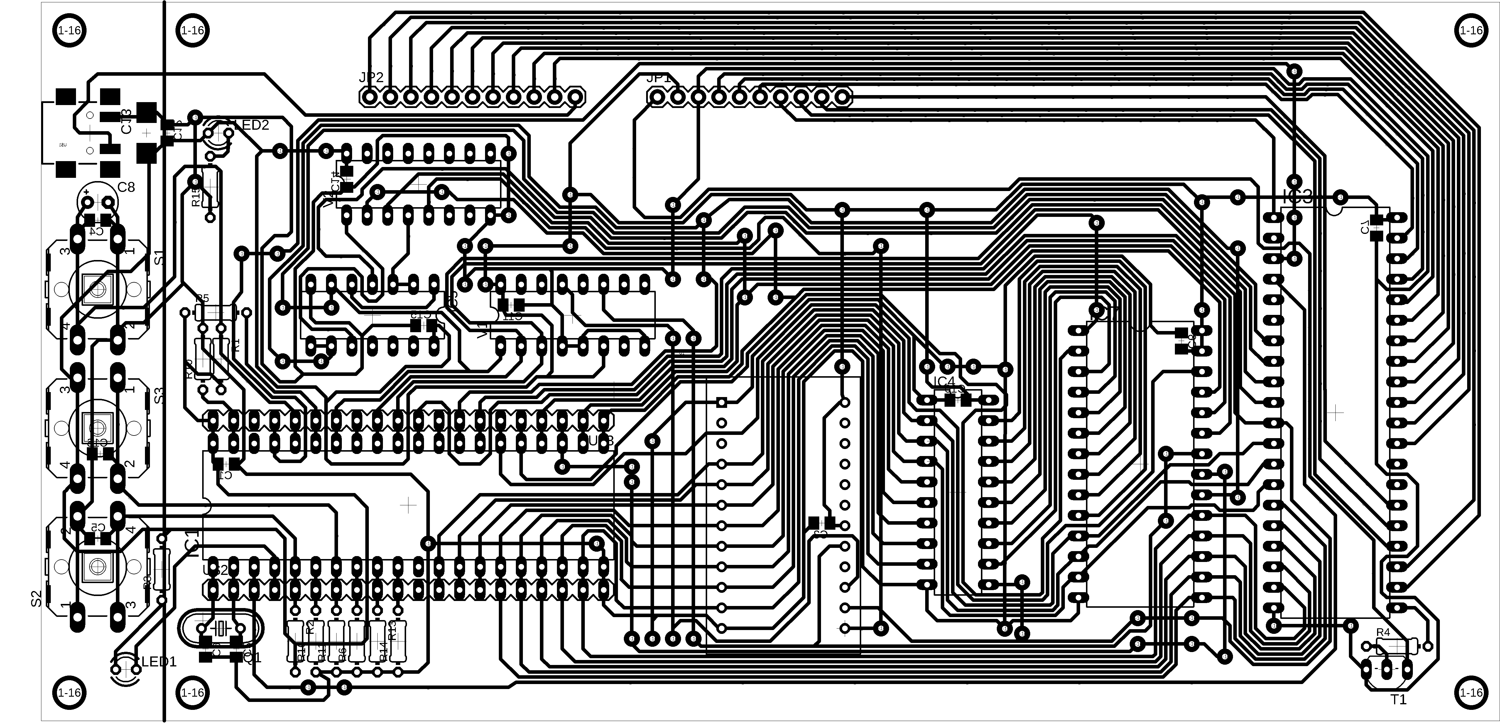
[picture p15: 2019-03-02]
images/Logicbrd(b).png

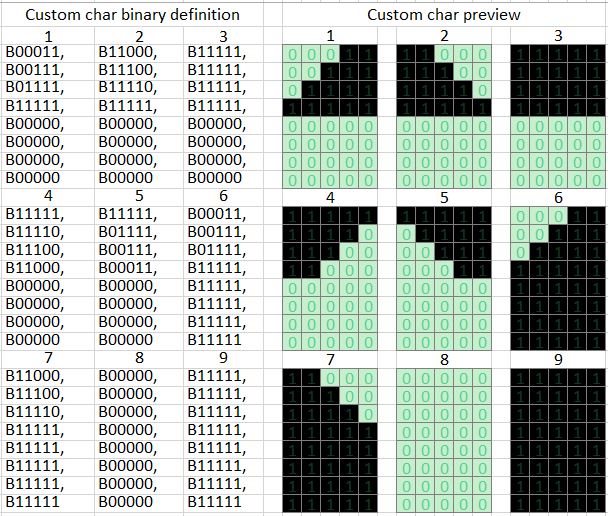
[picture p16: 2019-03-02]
images/customfont.JPG

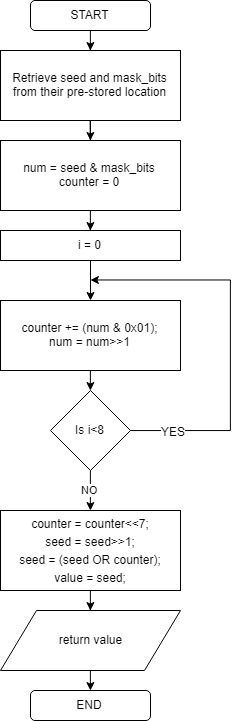
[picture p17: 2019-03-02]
images/LFSR.jpg

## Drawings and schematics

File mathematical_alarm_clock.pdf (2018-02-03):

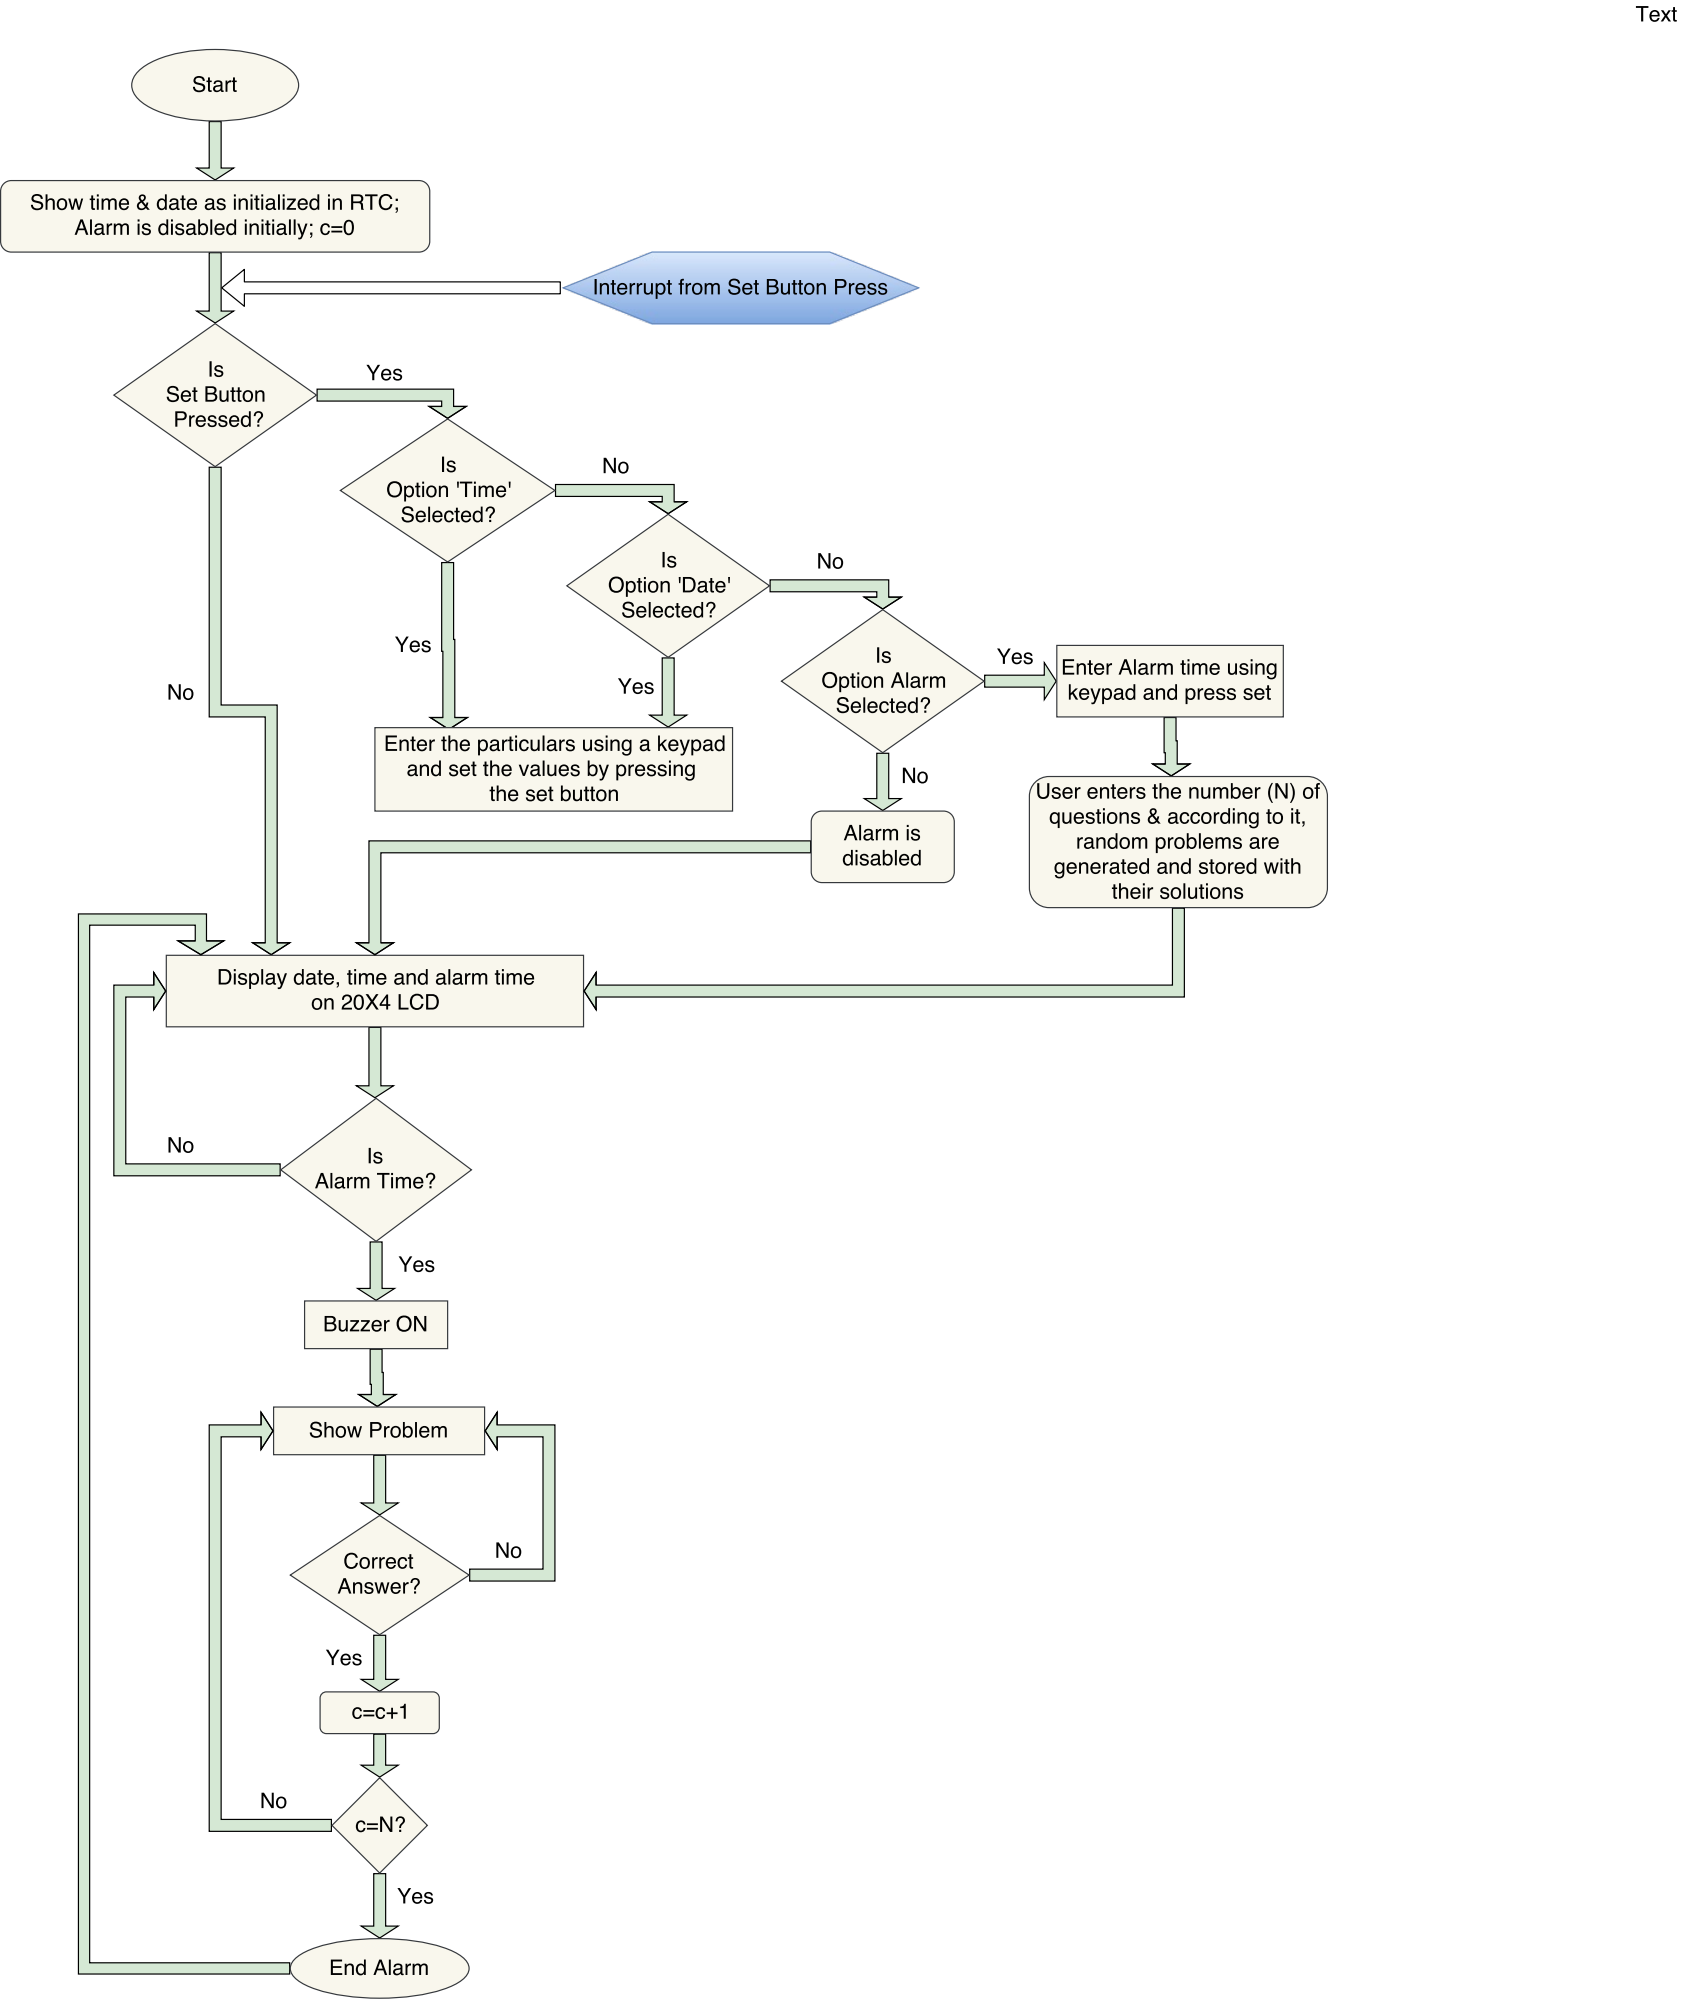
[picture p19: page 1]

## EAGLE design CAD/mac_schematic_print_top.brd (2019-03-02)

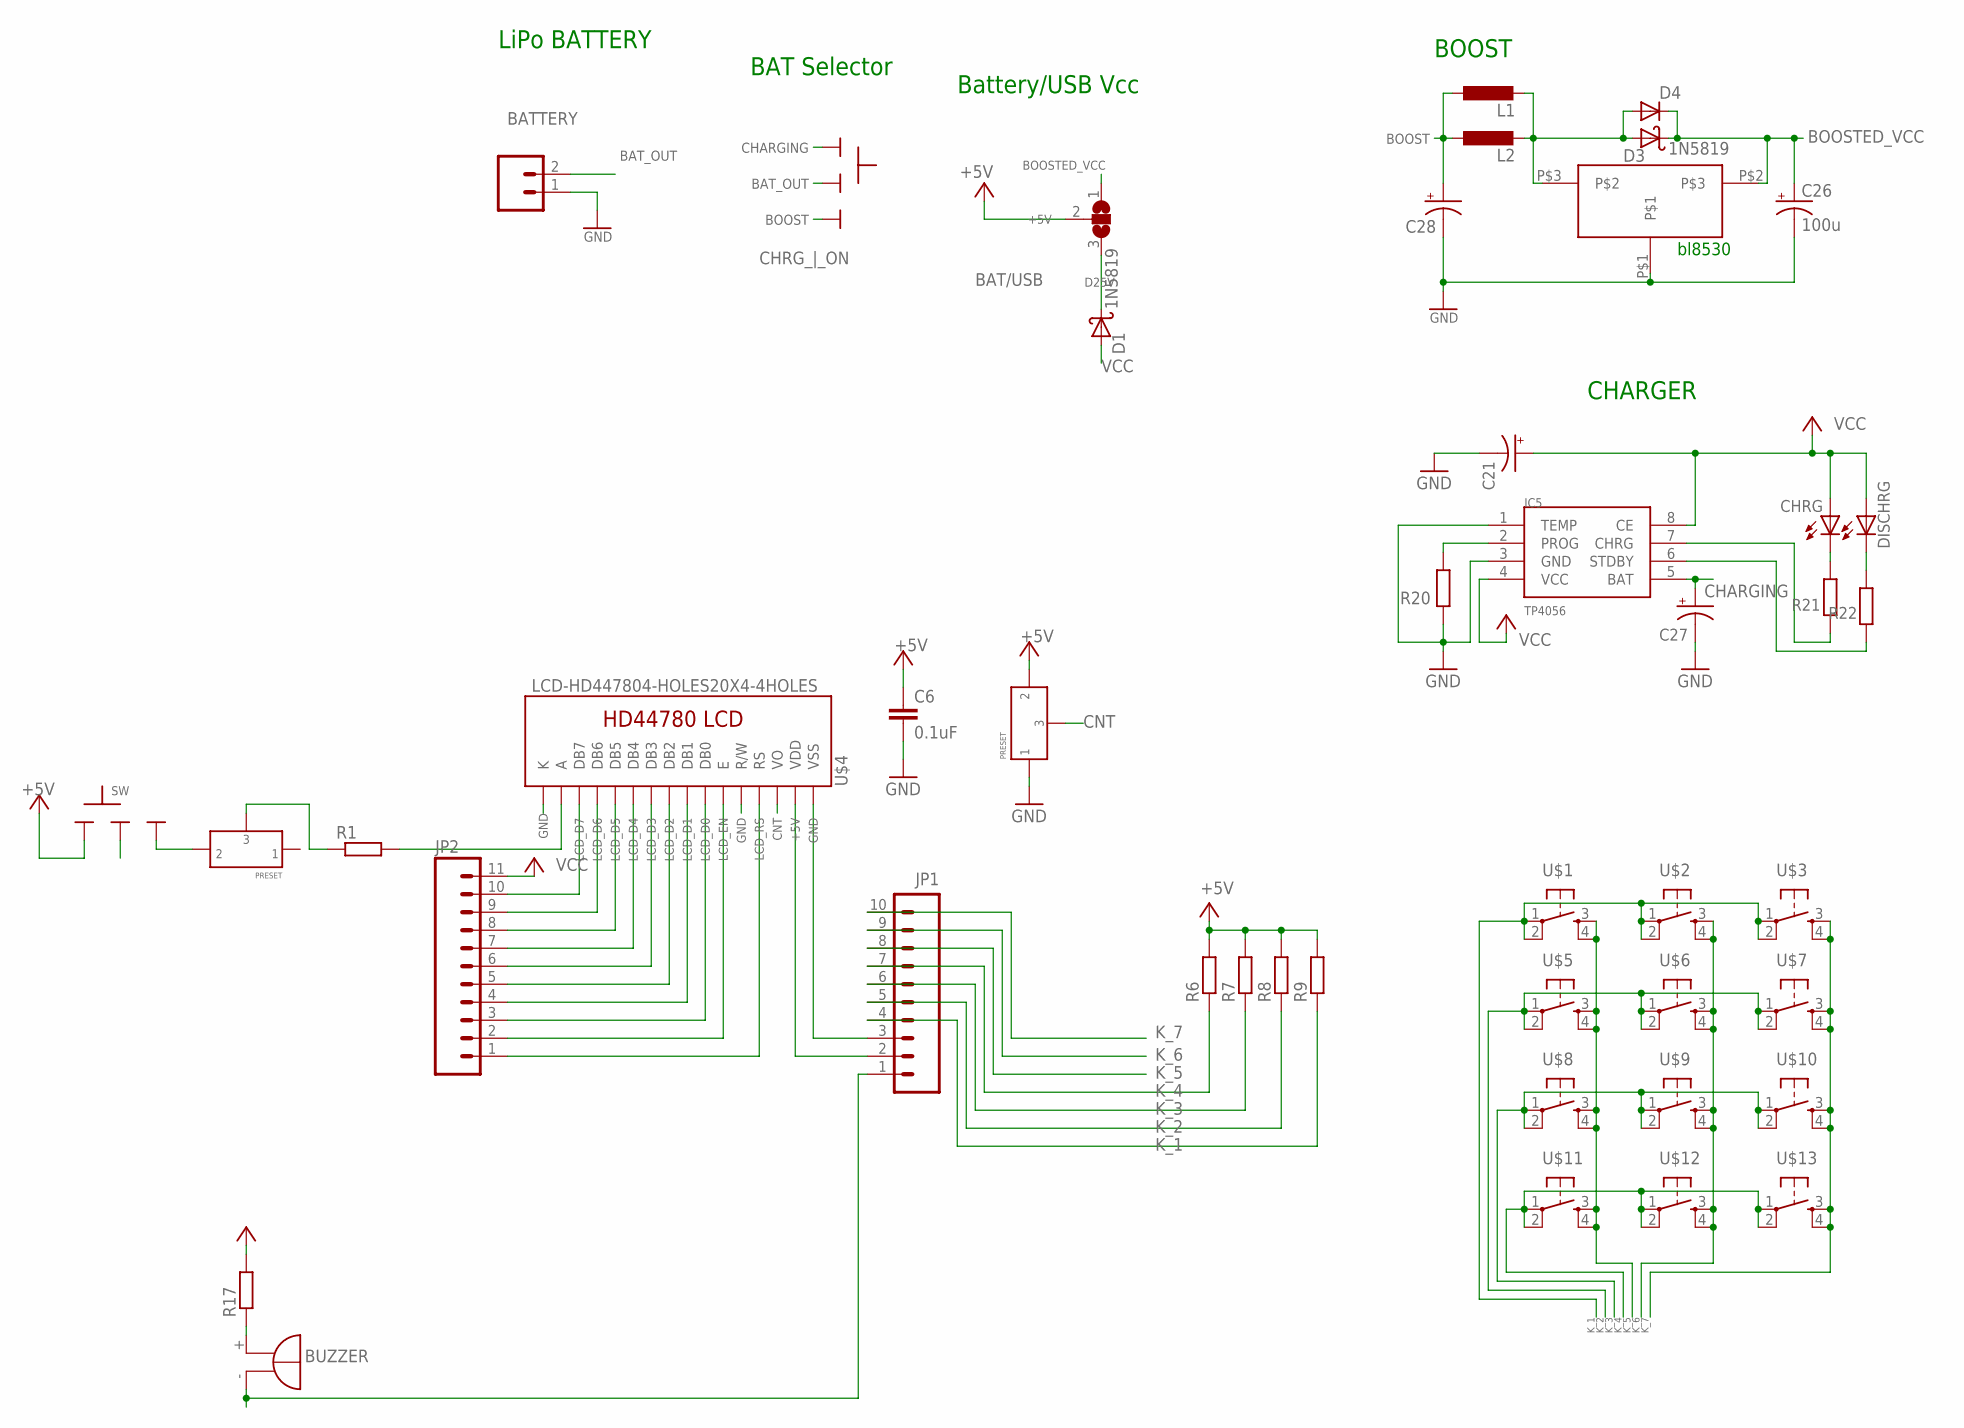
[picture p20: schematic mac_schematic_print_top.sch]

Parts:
BAT/USB: SJ2W; SJ_2
BATTERY: M02JST-PTH-2; 02P
C6: 0.1uF; C0805K
C21, C27, C28: 10u; C/6032-28R
C26: 100u; C/6032-28R
CHRG: LED3MM
CHRG_|_ON: SLIDESWITCH-BIG; BIGSWITCH
D1, D3: 1N5819; DO41-10
D4: DIODE_DIODE-DO214AC; DIODE_DO214AC
DISCHRG: LED3MM
IC5: TP4056; SOP-8
IC6: BL8530_5V
JP1: M10SILK_FEMALE_PTH; 1X10
JP2: M11PTH; 1X11
L1: L-EU6000-XXX-RC; 6000-XXXX-RC
L2: 47uH; L5650M
PRESET, PRESET1: PRESET; PRESET_LR
R1, R6, R7, R8, R9, R17, R20: R-EU_0204/7; 0204/7
R21, R22: 470; 0204/7
SG1: BUZZER; F/TMB
SW: SLIDESWITCH-BIG; BIGSWITCH
U$1, U$2, U$3, U$5, U$6, U$7, U$8, U$9, U$10, U$11, U$12, U$13: OMRON_SWITCH_40-XX; B3F-40XX
U$4: LCD-HD447804-HOLES20X4-4HOLES; LCD-20X4-4HOLES

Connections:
+5V: BAT/USB.2, C6.1, JP1.2, PRESET.P$2 (2), R6.2, R7.2, R8.2, R9.2, R17.2, SW.1, U$4.P$2 (VDD)
BAT_OUT: BATTERY.2, CHRG_|_ON.2
BOOST: C28.+, CHRG_|_ON.3, L1.1, L2.1
BOOSTED_VCC: BAT/USB.1, C26.+, D3.C, D4.C, IC6.P$2
CHARGING: C27.+, CHRG_|_ON.1, IC5.5 (BAT)
CNT: PRESET.P$3 (3), U$4.P$3 (VO)
D25V: BAT/USB.3, D1.C
GND: BATTERY.1, C6.2, C21.-, C26.-, C27.-, C28.-, IC5.1 (TEMP), IC5.3 (GND), IC6.P$1, JP1.3, PRESET.P$1 (1), R20.1, U$4.P$1 (VSS), U$4.P$5 (R/W), U$4.P$16 (K)
K_1: JP1.4, R9.1, U$1.1, U$1.2 (P1), U$2.1, U$2.2 (P1), U$3.1, U$3.2 (P1)
K_2: JP1.5, R8.1, U$5.1, U$5.2 (P1), U$6.1, U$6.2 (P1), U$7.1, U$7.2 (P1)
K_3: JP1.6, R7.1, U$8.1, U$8.2 (P1), U$9.1, U$9.2 (P1), U$10.1, U$10.2 (P1)
K_4: JP1.7, R6.1, U$11.1, U$11.2 (P1), U$12.1, U$12.2 (P1), U$13.1, U$13.2 (P1)
K_5: JP1.8, U$1.3 (S), U$1.4 (S1), U$5.3 (S), U$5.4 (S1), U$8.3 (S), U$8.4 (S1), U$11.3 (S), U$11.4 (S1)
K_6: JP1.9, U$2.3 (S), U$2.4 (S1), U$6.3 (S), U$6.4 (S1), U$9.3 (S), U$9.4 (S1), U$12.3 (S), U$12.4 (S1)
K_7: JP1.10, U$3.3 (S), U$3.4 (S1), U$7.3 (S), U$7.4 (S1), U$10.3 (S), U$10.4 (S1), U$13.3 (S), U$13.4 (S1)
LCD_D0: JP2.3, U$4.P$7 (DB0)
LCD_D1: JP2.4, U$4.P$8 (DB1)
LCD_D2: JP2.5, U$4.P$9 (DB2)
LCD_D3: JP2.6, U$4.P$10 (DB3)
LCD_D4: JP2.7, U$4.P$11 (DB4)
LCD_D5: JP2.8, U$4.P$12 (DB5)
LCD_D6: JP2.9, U$4.P$13 (DB6)
LCD_D7: JP2.10, U$4.P$14 (DB7)
LCD_EN: JP2.2, U$4.P$6 (E)
LCD_RS: JP2.1, U$4.P$4 (RS)
unnamed: JP1.1, SG1.-
unnamed: PRESET1.P$2 (2), SW.3
unnamed: R1.2, U$4.P$15 (A)
unnamed: PRESET1.P$3 (3), R1.1
unnamed: R17.1, SG1.+
unnamed: IC5.2 (PROG), R20.2
unnamed: IC5.7 (CHRG), R21.1
unnamed: IC5.6 (STDBY), R22.1
unnamed: CHRG.K (C), R21.2
unnamed: DISCHRG.K (C), R22.2
unnamed: D3.A, D4.A, IC6.P$3, L1.2, L2.2
VCC: C21.+, CHRG.A, D1.A, DISCHRG.A, IC5.4 (VCC), IC5.8 (CE), JP2.11

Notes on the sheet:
CHARGER
BOOST
bl8530
LiPo BATTERY
BAT Selector
Battery/USB Vcc

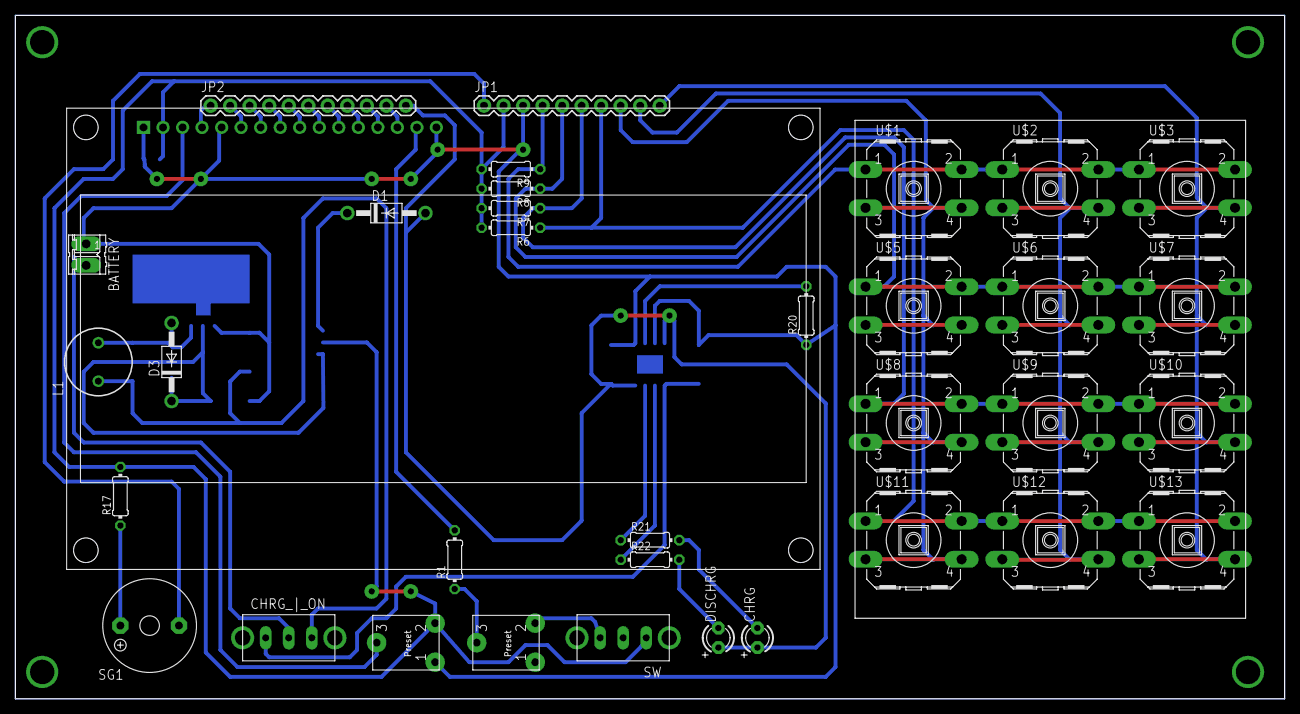
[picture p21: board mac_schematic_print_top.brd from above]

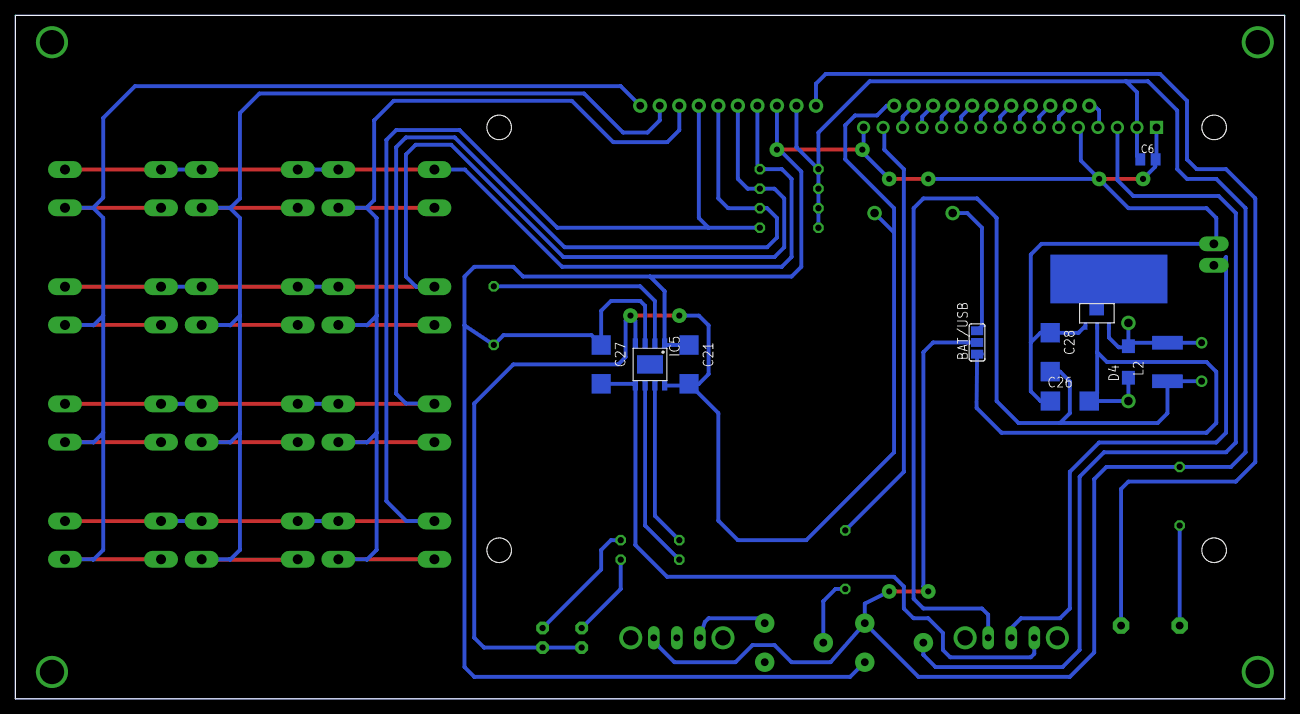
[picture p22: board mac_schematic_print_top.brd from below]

Board: 2 copper layers, 165.1 x 88.9 mm, 45 parts (10 on the bottom side), 37 nets.

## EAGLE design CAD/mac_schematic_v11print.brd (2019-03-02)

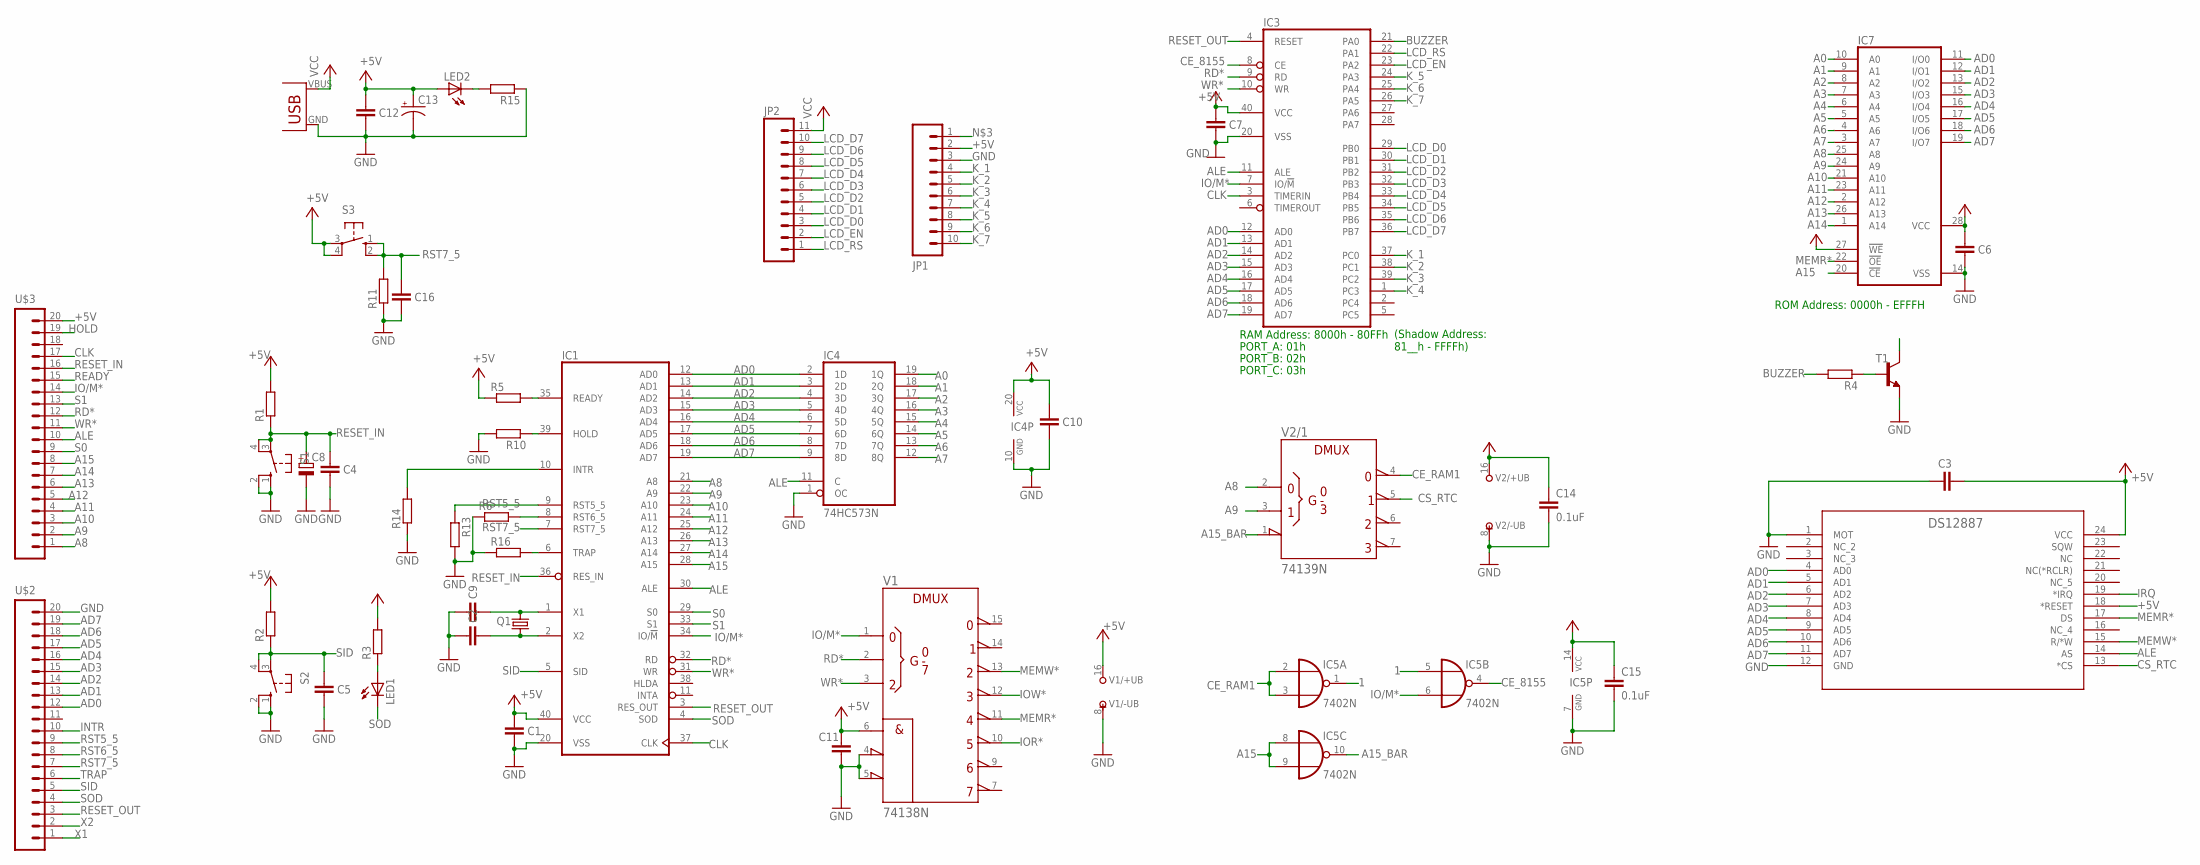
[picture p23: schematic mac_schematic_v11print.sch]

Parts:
C1, C2, C3, C4, C5, C6, C7, C9, C10, C11, C12, C16: C-EUC0805K; C0805K
C8: CPOL-EUE2.5-5; E2,5-5
C13: CAP_POL_10V; C/6032-28R
C14, C15: 0.1uF; C0805K
IC1: 8085; DIL40
IC3: 8155; DIL40
IC4: 74HC573N; DIL20
IC5: 7402N; DIL14
IC7: 58C256P; DIL28-6
JP1: M10SILK_FEMALE_PTH; 1X10
JP2: M11PTH; 1X11
LED1, LED2: LED3MM
Q1: CRYSTALHC49U-V; HC49U-V
R1, R2, R3, R4, R5, R6, R10, R11, R13, R14, R15, R16: R-EU_0204/7; 0204/7
S1, S2, S3: 40-XX; B3F-40XX
T1: BC547-NPN-TO92-CBE; TO92-CBE
U1: DS12887; 21-0241A_24
U$1: USB(POWER)
U$2, U$3: M20; LONDPAD
V1: 74138N; DIL16
V2: 74139N; DIL16

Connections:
1: IC5.1 (O), IC5.5 (I0)
+5V: C1.1, C3.2, C6.1, C7.1, C10.1, C11.1, C12.1, C13.+, C14.1, C15.1, IC1.40 (VCC), IC3.40 (VCC), IC4.20 (VCC), IC5.14 (VCC), IC7.27 (!WE), IC7.28 (VCC), JP1.2, LED2.A, R1.2, R2.2, R3.2, R5.1, S3.3, S3.4 (P1), U1.18 (*RESET), U1.24 (VCC), U$3.20, V1.6 (G1), V1.16 (+UB), V2.16 (+UB)
A0: IC4.19 (1Q), IC7.10 (A0)
A1: IC4.18 (2Q), IC7.9 (A1)
A2: IC4.17 (3Q), IC7.8 (A2)
A3: IC4.16 (4Q), IC7.7 (A3)
A4: IC4.15 (5Q), IC7.6 (A4)
A5: IC4.14 (6Q), IC7.5 (A5)
A6: IC4.13 (7Q), IC7.4 (A6)
A7: IC4.12 (8Q), IC7.3 (A7)
A8: IC1.21 (A8), IC7.25 (A8), U$3.1, V2.2 (A)
A9: IC1.22 (A9), IC7.24 (A9), U$3.2, V2.3 (B)
A10: IC1.23 (A10), IC7.21 (A10), U$3.3
A11: IC1.24 (A11), IC7.23 (A11), U$3.4
A12: IC1.25 (A12), IC7.2 (A12), U$3.5
A13: IC1.26 (A13), IC7.26 (A13), U$3.6
A14: IC1.27 (A14), IC7.1 (A14), U$3.7
A15: IC1.28 (A15), IC5.8 (I0), IC5.9 (I1), IC7.20 (!CE), U$3.8
A15_BAR: IC5.10 (O), V2.1 (!G)
AD0: IC1.12 (AD0), IC3.12 (AD0), IC4.2 (1D), IC7.11 (I/O0), U1.4 (AD0), U$2.12
AD1: IC1.13 (AD1), IC3.13 (AD1), IC4.3 (2D), IC7.12 (I/O1), U1.5 (AD1), U$2.13
AD2: IC1.14 (AD2), IC3.14 (AD2), IC4.4 (3D), IC7.13 (I/O2), U1.6 (AD2), U$2.14
AD3: IC1.15 (AD3), IC3.15 (AD3), IC4.5 (4D), IC7.15 (I/O3), U1.7 (AD3), U$2.15
AD4: IC1.16 (AD4), IC3.16 (AD4), IC4.6 (5D), IC7.16 (I/O4), U1.8 (AD4), U$2.16
AD5: IC1.17 (AD5), IC3.17 (AD5), IC4.7 (6D), IC7.17 (I/O5), U1.9 (AD5), U$2.17
AD6: IC1.18 (AD6), IC3.18 (AD6), IC4.8 (7D), IC7.18 (I/O6), U1.10 (AD6), U$2.18
AD7: IC1.19 (AD7), IC3.19 (AD7), IC4.9 (8D), IC7.19 (I/O7), U1.11 (AD7), U$2.19
ALE: IC1.30 (ALE), IC3.11 (ALE), IC4.11 (C), U1.14 (AS), U$3.10
BUZZER: IC3.21 (PA0), R4.2
CE_8155: IC3.8 (CE), IC5.4 (O)
CE_RAM1: IC5.2 (I0), IC5.3 (I1), V2.4 (Y0)
CLK: IC1.37 (CLK), IC3.3 (TIMERIN), U$3.17
CS_RTC: U1.13 (*CS), V2.5 (Y1)
GND: C1.2, C2.1, C3.1, C4.2, C5.2, C6.2, C7.2, C8.-, C9.1, C10.2, C11.2, C12.2, C13.-, C14.2, C15.2, C16.2, IC1.20 (VSS), IC3.20 (VSS), IC4.1 (OC), IC4.10 (GND), IC5.7 (GND), IC7.14 (VSS), JP1.3, R6.1, R10.2, R11.1, R13.2, R14.1, R15.1, R16.1, S1.1 (S), S1.2 (S1), S2.1 (S), S2.2 (S1), T1.E, U1.1 (MOT), U1.12 (GND), U$1.GND, U$2.20, V1.4 (!G2A), V1.5 (!G2B), V1.8 (-UB), V2.8 (-UB)
HOLD: IC1.39 (HOLD), R10.1, U$3.19
INTR: IC1.10 (INTR), R14.2, U$2.10
IO/M*: IC1.34 (IO/!M), IC3.7 (IO/!M), IC5.6 (I1), U$3.14, V1.1 (A)
IOR*: V1.10 (Y5)
IOW*: V1.12 (Y3)
IRQ: U1.19 (*IRQ)
K_1: IC3.37 (PC0), JP1.4
K_2: IC3.38 (PC1), JP1.5
K_3: IC3.39 (PC2), JP1.6
K_4: IC3.1 (PC3), JP1.7
K_5: IC3.24 (PA3), JP1.8
K_6: IC3.25 (PA4), JP1.9
K_7: IC3.26 (PA5), JP1.10
LCD_D0: IC3.29 (PB0), JP2.3
LCD_D1: IC3.30 (PB1), JP2.4
LCD_D2: IC3.31 (PB2), JP2.5
LCD_D3: IC3.32 (PB3), JP2.6
LCD_D4: IC3.33 (PB4), JP2.7
LCD_D5: IC3.34 (PB5), JP2.8
LCD_D6: IC3.35 (PB6), JP2.9
LCD_D7: IC3.36 (PB7), JP2.10
LCD_EN: IC3.23 (PA2), JP2.2
LCD_RS: IC3.22 (PA1), JP2.1
MEMR*: IC7.22 (!OE), U1.17 (DS), V1.11 (Y4)
MEMW*: U1.15 (R/*W), V1.13 (Y2)
unnamed: LED1.A, R3.1
unnamed: JP1.1, T1.C
unnamed: R4.1, T1.B
unnamed: LED2.K (C), R15.2
RD*: IC1.32 (RD), IC3.9 (RD), U$3.12, V1.2 (B)
READY: IC1.35 (READY), R5.2, U$3.15
RESET_IN: C4.1, C8.+, IC1.36 (RES_IN), R1.1, S1.3, S1.4 (P1), U$3.16
RESET_OUT: IC1.3 (RES_OUT), IC3.4 (RESET), U$2.3
RST5_5: IC1.9 (RST5_5), R13.1, U$2.9
RST6_5: IC1.8 (RST6_5), R6.2, U$2.8
RST7_5: C16.1, IC1.7 (RST7_5), R11.2, S3.1 (S), S3.2 (S1), U$2.7
S0: IC1.29 (S0), U$3.9
S1: IC1.33 (S1), U$3.13
SID: C5.1, IC1.5 (SID), R2.1, S2.3, S2.4 (P1), U$2.5
SOD: IC1.4 (SOD), LED1.K (C), U$2.4
TRAP: IC1.6 (TRAP), R16.2, U$2.6
VCC: JP2.11, U$1.VBUS (VCC)
WR*: IC1.31 (WR), IC3.10 (WR), U$3.11, V1.3 (C)
X1: C9.2, IC1.1 (X1), Q1.2, U$2.1
X2: C2.2, IC1.2 (X2), Q1.1, U$2.2

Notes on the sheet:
ROM Address: 0000h - EFFFH
RAM Address: 8000h - 80FFh
PORT_A: 01h
PORT_B: 02h
PORT_C: 03h
(Shadow Address: 81__h - FFFFh)

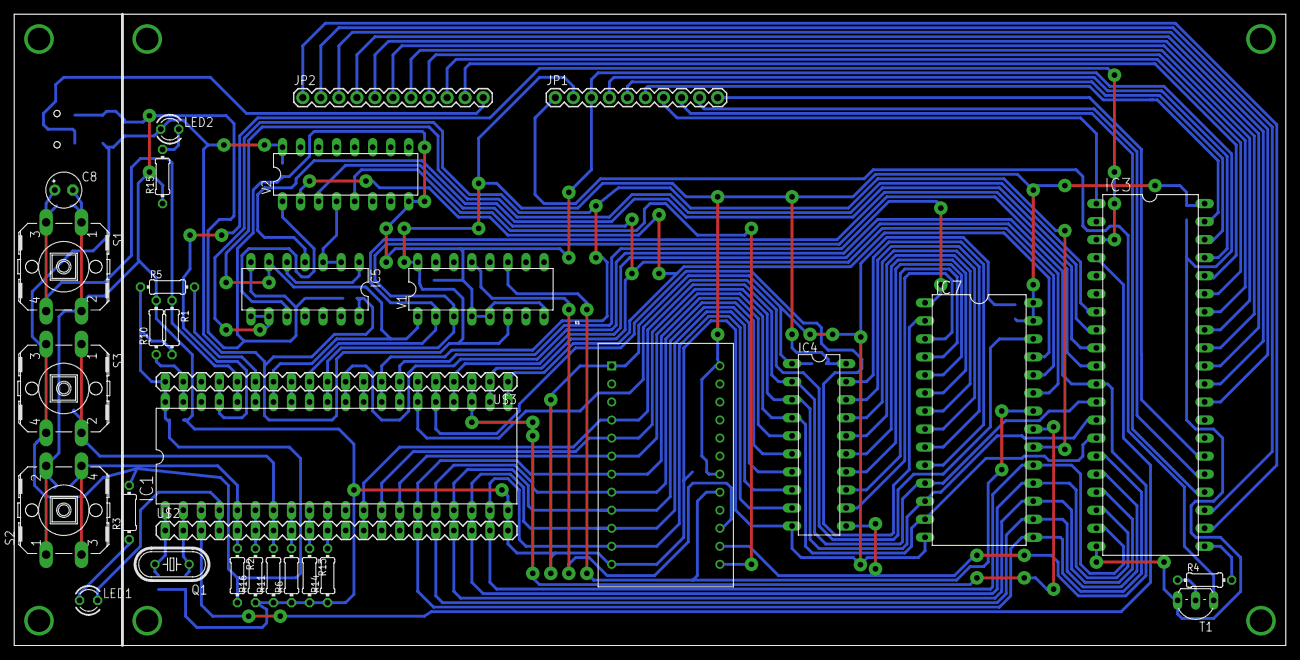
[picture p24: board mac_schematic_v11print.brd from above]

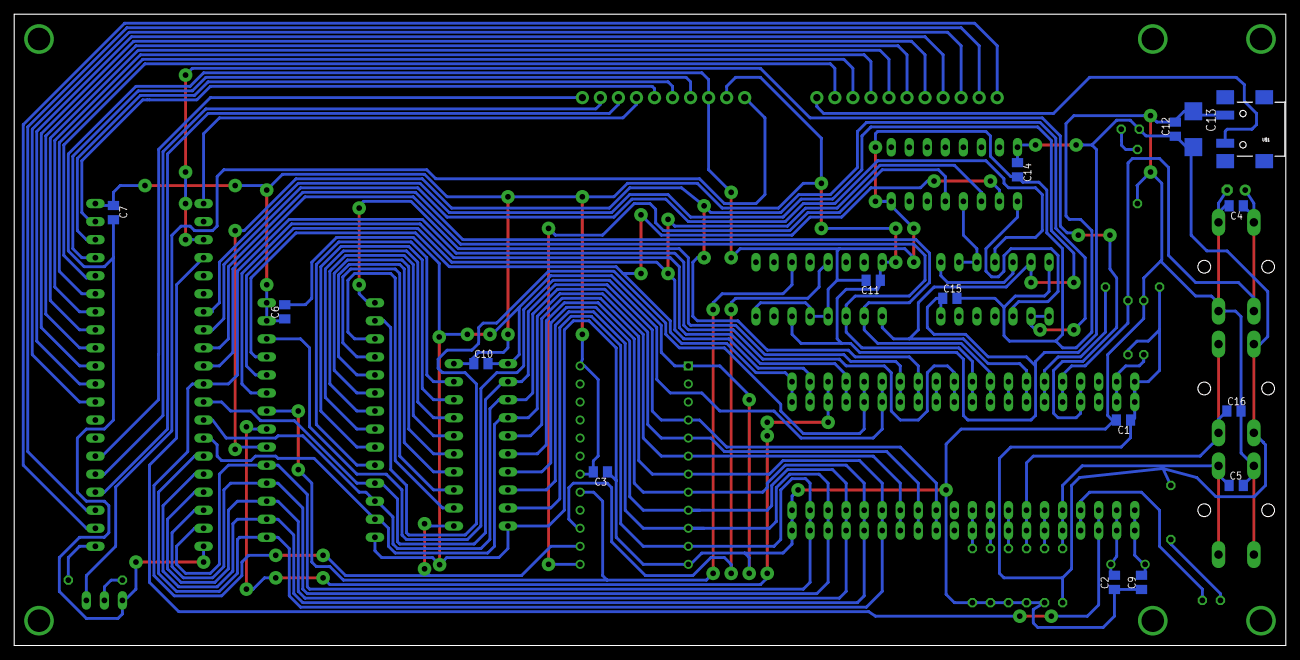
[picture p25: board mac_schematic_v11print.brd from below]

Board: 2 copper layers, 179.1 x 88.9 mm, 48 parts (16 on the bottom side), 76 nets.

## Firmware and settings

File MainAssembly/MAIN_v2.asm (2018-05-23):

LCDRS EQU 02H
LCDEN EQU 04H
PORTA EQU 01H
PORTB EQU 02H
PORTC EQU 03H
RTCSEC EQU 8100H
RTCASEC EQU 8101H
RTCMIN EQU 8102H
RTCAMIN EQU 8103H
RTCHR EQU 8104H
RTCAHR EQU 8105H
RTCDAYWEEK EQU 8106H
RTCDAYMONTH EQU 8107H
RTCMONTH EQU 8108H
RTCYEAR EQU 8109H
RTCA EQU 810AH
RTCB EQU 810BH
RTCC EQU 810CH
PRESSED EQU 8116H
NEXTBTN EQU 8002H
SETSTATE EQU 8003H
TEMPSWAP1 EQU 8004H
TEMPSWAP2 EQU 8005H
PPICSR EQU 00H

ALARMPREV EQU 8117H
SEED EQU 8111H
BITS EQU 8112H
NUM1 EQU 8113H
NUM2 EQU 8114H
OPR EQU 8115H
RESULT EQU 8006H
ANSWER EQU 8007H

.ORG 0000H
	JMP 1100H
.ORG 003CH
	JMP RST7_5ISR
	
.ORG 1000H
DATA DB 03H,07H,0FH,1FH,00H,00H,00H,00H,18H,1CH,1EH,1FH,00H,00H,00H,00H
.DB 1FH,1FH,1FH,1FH
.DB 00H,00H,00H,00H
.DB 1FH,1EH,1CH,18H
.DB 00H,00H,00H,00H
.DB 1FH,0FH,07H,03H
.DB 00H,00H,00H,00H
.DB 03H,07H,0FH,1FH
.DB 1FH,1FH,1FH,1FH
.DB 18H,1CH,1EH,1FH
.DB 1FH,1FH,1FH,1FH

.ORG 1040H
DATA_SETTINGS DB 53H,65H,74H,74H,69H,6EH,67H,73H

.ORG 104AH
DATA_TIME DB 28H,31H,29H,0FEH,54H,69H,6DH,65H

.ORG 1053H
DATA_ALAM DB 28H,32H,29H,0FEH,41H,6CH,61H,72H,6DH

.ORG 105DH
DATA_ENTER DB 45H,6EH,74H,65H,72H,0FEH,79H,6FH,75H,72H,0FEH,63H,68H,6FH,69H,63H
.DB 65H,3AH,00H,00H

.ORG 1070H
DATA_HOUR DB 48H,6FH,75H,72H,73H,3AH

.ORG 1077H
DATA_MIN DB 4DH,69H,6EH,75H,74H,65H,73H,3AH

.ORG 1100H

MAININIT:	
		LXI SP,80FFH
		CALL PPINIT
		CALL DELAY_200MS
		CALL LCD_INIT
		CALL CGINIT
		;MVI A,0AEh
		;STA SEED
		;MVI A,2Dh
		;STA BITS
		MVI A,20h
		STA RTCA
		MVI A,03h
		STA RTCB
		MVI A,0Bh
		SIM
		EI

MAIN:		CALL NORMALDISP
		CALL ALARMCHK
		JMP MAIN

ALARMCHK:
		PUSH PSW
		LXI H,ALARMPREV
		MOV A,M
		CPI 01H
		JZ ALAM_AGAIN
		LDA RTCC
		ANI 20H
		CPI 20H
		JNZ ENDALARMCHK
		DI
		LXI H,ALARMPREV
		MVI M,01H
		
ALAM_AGAIN:
		CALL PROBGEN
		IN PORTA
		ORI 01H
		OUT PORTA
		
		MVI C,01h	;clear lcd
		CALL SEND_CMD
		MVI C,0C7H
		CALL SEND_CMD
		LXI H,NUM1
		MOV B,M
		;CALL HEXTOBCD
		CALL HEXTODECI
		CALL DDSEND
		MVI C,2BH
		CALL SEND_DATA
		LXI H,NUM2
		MOV B,M
		;CALL HEXTOBCD
		CALL HEXTODECI
		CALL DDSEND
		MVI C,3DH
		CALL SEND_DATA
		LXI H,RESULT
		MOV B,M
		;CALL HEXTOBCD
		CALL HEXTODECI
		LXI H,RESULT
		MOV M,B
		;CALL DDSEND
		MVI C,0FH
		CALL SEND_CMD
		CALL KEYPAD
		LXI H,PRESSED
		MOV A,M
		RLC 
		RLC
		RLC
		RLC
		ANI 0F0h
		MOV E,A
		LDA PRESSED
		ADI 30H
		MOV C,A
		CALL SEND_DATA
		CALL KEYPAD
		LXI H,PRESSED
		MOV A,M
		ORA E
		MOV E,A
		MOV A,E
		STA ANSWER
		LDA PRESSED
		ADI 30H
		MOV C,A
		CALL SEND_DATA
		CALL DELAY_500MS
		

		LXI H,RESULT
		LDA ANSWER
		CMP M
		JNZ ALAM_AGAIN

		;MVI C,0AH
DELALAM:	;MVI B,0FFH
DELALAM1:	
		;CALL DELAY_2MS
		;IN PORTA
		;ORI 01H
		;OUT PORTA
		;CALL DELAY_2MS
		;IN PORTA
		;ANI 0FEH
		;OUT PORTA
		;DCR B
		;JNZ DELALAM1
		;DCR C
		;JNZ DELALAM
		
		IN PORTA
		ANI 0FEH
		OUT PORTA
		MVI C,01h	;clear lcd
		CALL SEND_CMD
ENDALARMCHK:
		LXI H,ALARMPREV
		MVI M,00H
		EI
		POP PSW
		RET

NORMALDISP:
		PUSH PSW

		MVI C,80H
		CALL SEND_CMD

		LXI H,RTCDAYMONTH
		MOV B,M
		CALL DDSEND

		MVI C,2FH
		CALL SEND_DATA

		LXI H,RTCMONTH
		MOV B,M
		CALL DDSEND

		MVI C,2FH
		CALL SEND_DATA

		LXI H,RTCYEAR
		MOV B,M
		CALL DDSEND


		MVI C,89H 	;cursor is set here must auto increment till ots set again
		CALL SEND_CMD
		LXI H,DATA_ALAM
		INX H
		INX H
		INX H
		INX H
		MVI B,05h
L0:		MOV C,M 		; to display "Alarm-"
		CALL SEND_DATA
		DCR B
		JZ HERE
		INX H
		JMP L0

HERE:		MVI C,0FEH	
		CALL SEND_DATA
		LXI H,RTCAHR
		MOV B,M 		;supposed to display alarm time or infact anything other than 0, wht do you think?
		CALL DDSEND
		
		MVI C,3AH	
		CALL SEND_DATA
		
		LXI H,RTCAMIN
		MOV B,M 		;supposed to display alarm time or infact anything other than 0, wht do you think?
		CALL DDSEND	

		MVI D,06h
		LXI H,RTCHR
L3:		MOV A,M
		ANI 0F0h
		RRC		
		RRC
		RRC
		RRC

		MOV C,A
		MOV A,D
		CALL DECPS
		DCR D
		MOV A,M
		ANI 0Fh

		MOV C,A
		MOV A,D
		CALL DECPS
		DCX H
		DCX H
		DCR D
		JNZ L3

		POP PSW
		RET



PROBGEN:	PUSH PSW
		PUSH B
		LXI H,NUM1
		CALL RANDOM
		LXI H,NUM2
		CALL RANDOM
		LDA NUM1
		LXI H,NUM2
		ADD M
		STA RESULT
ENDPROB:	POP B
		POP PSW
		RET

RANDOM:		PUSH PSW ;ADDRESS PASSED IN H WHERE THE VAL SHOULD BE STORED
		PUSH B
		PUSH D
		MVI B,01H
LOOP3:		MVI D,01H
LOOP2:		CALL LFSR
		LDA SEED
		CPI 31
		JNC LOOP2
		;STC
		;CMC
		;RAR
		;STC 
		;CMC
		;RAR
		;CPI 32H
		;JNC LOOP2
		DCR D
		JNZ LOOP2
		DCR B
		JNZ LOOP3
		LDA SEED
		MOV M,A
		POP D
		POP B
		POP PSW
		RET

LFSR:	PUSH PSW ;RET VAL IN THE SEED LOC
		PUSH B
		PUSH D
		PUSH H
		LXI H,SEED
		MOV A,M
		LXI H,BITS
		ANA M
		MVI B,00H
		MVI C,08H
LOOP1:	RRC
		JNC NXT1
		INR B
NXT1:	DCR C
		JNZ LOOP1
		MOV A,B
		RLC
		RLC
		RLC
		RLC
		RLC
		RLC
		RLC
		ANI 80H
		MOV B,A
		LXI H,SEED
		MOV A,M
		STC
		CMC
		RAR
		ORA B
		STA SEED
		POP H
		POP D
		POP B
		POP PSW
		RET

CGINIT:	PUSH PSW
		PUSH B
		MVI C,40h
		CALL SEND_CMD
		MVI B,38h
		LXI H,DATA

BLKAGAIN:	   MOV C,M
	   CALL SEND_DATA
	   INX H
	   DCR B
	   JNZ BLKAGAIN
	   POP B
	   POP PSW
	   RET

DECPS:	   PUSH PSW
	   PUSH B
	   PUSH D
	   CPI 06h
	   JNZ HR2
	   MVI D,0C0h
	   MVI B,94h
	   MVI E,0D4h
	   CALL DECDAT
	   JMP CGEND

HR2:	   CPI 05h
	   JNZ MIN1L
	   MVI D,0C3h
	   MVI B,97h
	   MVI E,0D7h
	   CALL DECDAT
	   JMP CGEND

MIN1L:	   CPI 04h
	   JNZ MIN2
	   MVI D,0C7h
	   MVI B,09Bh
	   MVI E,0DBh
	   CALL DECDAT
	   JMP CGEND

MIN2:	   CPI 03h
	   JNZ SEC1
	   MVI D,0CAh
	   MVI B,09Eh
	   MVI E,0DEh
	   CALL DECDAT
	   JMP CGEND

SEC1:	   CPI 02h
	   JNZ SEC2
	   MVI D,0CEh
	   MVI B,0A2h
	   MVI E,0E2h
	   CALL DECDAT
	   JMP CGEND

SEC2:	   MVI D,0D1h
	   MVI B,0A5h
	   MVI E,0E5h
	   CALL DECDAT

CGEND:	   POP D
	   POP B
	   POP PSW
	   RET

DECDAT:	   MOV A,C
	   CPI 00h
	   JNZ ONE
	   MOV C,D
	   CALL SEND_CMD
	   MVI C,05h
	   CALL SEND_DATA
	   MVI C,02h
	   CALL SEND_DATA
	   MVI C,06h
	   CALL SEND_DATA
	   MOV C,B
	   CALL SEND_CMD
	   MVI C,0FFh
	   CALL SEND_DATA
	   MVI C,0FEh
	   CALL SEND_DATA
	   MVI C,0FFh
	   CALL SEND_DATA
	   MOV C,E
	   CALL SEND_CMD
	   MVI C,04h
	   CALL SEND_DATA
	   MVI C,02h
	   CALL SEND_DATA
	   MVI C,03h
	   CALL SEND_DATA
	   RET

ONE:	   CPI 01h
	   JNZ TWO
	   MOV C,D
	   CALL SEND_CMD
	   MVI C,00h
	   CALL SEND_DATA
	   MVI C,0FFh
	   CALL SEND_DATA
	   MVI C,0FEh
	   CALL SEND_DATA
	   MOV C,B
	   CALL SEND_CMD
	   MVI C,0FEh
	   CALL SEND_DATA
	   MVI C,0FFh
	   CALL SEND_DATA
	   MVI C,0FEh
	   CALL SEND_DATA
	   MOV C,E
	   CALL SEND_CMD
	   MVI C,02h
	   CALL SEND_DATA
	   MVI C,02h
	   CALL SEND_DATA
	   MVI C,02h
	   CALL SEND_DATA
	   RET

TWO:	   CPI 02h
	   JNZ THREE
	   MOV C,D
	   CALL SEND_CMD
	   MVI C,00h
	   CALL SEND_DATA
	   MVI C,02h
	   CALL SEND_DATA
	   MVI C,06h
	   CALL SEND_DATA
	   MOV C,B
	   CALL SEND_CMD
	   MVI C,05h
	   CALL SEND_DATA
	   MVI C,02h
	   CALL SEND_DATA
	   MVI C,03h
	   CALL SEND_DATA
	   MOV C,E
	   CALL SEND_CMD
	   MVI C,02h
	   CALL SEND_DATA
	   MVI C,02h
	   CALL SEND_DATA
	   MVI C,02h
	   CALL SEND_DATA
	   RET

THREE:	   CPI 03h
	   JNZ FOUR
	   MOV C,D
	   CALL SEND_CMD
	   MVI C,00h
	   CALL SEND_DATA
	   MVI C,02h
	   CALL SEND_DATA
	   MVI C,06h
	   CALL SEND_DATA
	   MOV C,B
	   CALL SEND_CMD
	   MVI C,0FEh
	   CALL SEND_DATA
	   MVI C,02h
	   CALL SEND_DATA
	   MVI C,0FFh
	   CALL SEND_DATA
	   MOV C,E
	   CALL SEND_CMD
	   MVI C,04h
	   CALL SEND_DATA
	   MVI C,02h
	   CALL SEND_DATA
	   MVI C,03h
	   CALL SEND_DATA
	   RET

FOUR:	   CPI 04h
	   JNZ FIVE
	   MOV C,D
	   CALL SEND_CMD
	   MVI C,0FFh
	   CALL SEND_DATA
	   MVI C,0FEh
	   CALL SEND_DATA
	   MVI C,0FFh
	   CALL SEND_DATA
	   MOV C,B
	   CALL SEND_CMD
	   MVI C,04h
	   CALL SEND_DATA
	   MVI C,02h
	   CALL SEND_DATA
	   MVI C,0FFh
	   CALL SEND_DATA
	   MOV C,E
	   CALL SEND_CMD
	   MVI C,0FEh
	   CALL SEND_DATA
	   MVI C,0FEh
	   CALL SEND_DATA
	   MVI C,02h
	   CALL SEND_DATA
	   RET

FIVE:	   CPI 05h
	   JNZ SIX
	   MOV C,D
	   CALL SEND_CMD
	   MVI C,0FFh
	   CALL SEND_DATA
	   MVI C,02h
	   CALL SEND_DATA
	   MVI C,03h
	   CALL SEND_DATA
	   MOV C,B
	   CALL SEND_CMD
	   MVI C,02h
	   CALL SEND_DATA
	   MVI C,02h
	   CALL SEND_DATA
	   MVI C,06h
	   CALL SEND_DATA
	   MOV C,E
	   CALL SEND_CMD
	   MVI C,04h
	   CALL SEND_DATA
	   MVI C,02h
	   CALL SEND_DATA
	   MVI C,03h
	   CALL SEND_DATA
	   RET

SIX:	   CPI 06h
	   JNZ SEVEN
	   MOV C,D
	   CALL SEND_CMD
	   MVI C,05h
	   CALL SEND_DATA
	   MVI C,02h
	   CALL SEND_DATA
	   MVI C,01h
	   CALL SEND_DATA
	   MOV C,B
	   CALL SEND_CMD
	   MVI C,0FFh
	   CALL SEND_DATA
	   MVI C,02h
	   CALL SEND_DATA
	   MVI C,06h
	   CALL SEND_DATA
	   MOV C,E
	   CALL SEND_CMD
	   MVI C,04h
	   CALL SEND_DATA
	   MVI C,02h
	   CALL SEND_DATA
	   MVI C,03h
	   CALL SEND_DATA
	   RET

SEVEN:	   CPI 07h
	   JNZ L8T
	   MOV C,D
	   CALL SEND_CMD
	   MVI C,04h
	   CALL SEND_DATA
	   MVI C,02h
	   CALL SEND_DATA
	   MVI C,0FFh
	   CALL SEND_DATA
	   MOV C,B
	   CALL SEND_CMD
	   MVI C,0FEh
	   CALL SEND_DATA
	   MVI C,05h
	   CALL SEND_DATA
	   MVI C,03h
	   CALL SEND_DATA
	   MOV C,E
	   CALL SEND_CMD
	   MVI C,0FEh
	   CALL SEND_DATA
	   MVI C,02h
	   CALL SEND_DATA
	   MVI C,0FEh
	   CALL SEND_DATA
	   RET

L8T:	   CPI 08h
	   JNZ NINE
	   MOV C,D
	   CALL SEND_CMD
	   MVI C,05h
	   CALL SEND_DATA
	   MVI C,02h
	   CALL SEND_DATA
	   MVI C,06h
	   CALL SEND_DATA
	   MOV C,B
	   CALL SEND_CMD
	   MVI C,05h
	   CALL SEND_DATA
	   MVI C,02h
	   CALL SEND_DATA
	   MVI C,06h
	   CALL SEND_DATA
	   MOV C,E
	   CALL SEND_CMD
	   MVI C,04h
	   CALL SEND_DATA
	   MVI C,02h
	   CALL SEND_DATA
	   MVI C,03h
	   CALL SEND_DATA
	   RET

NINE:	   MOV C,D
		CALL SEND_CMD
		MVI C,05h
		CALL SEND_DATA
		MVI C,02h
		CALL SEND_DATA
		MVI C,06h
		CALL SEND_DATA
		MOV C,B
		CALL SEND_CMD
		MVI C,04h
		CALL SEND_DATA
		MVI C,02h
		CALL SEND_DATA
		MVI C,0FFh
		CALL SEND_DATA
		MOV C,E
		CALL SEND_CMD
		MVI C,04h
		CALL SEND_DATA
		MVI C,02h
		CALL SEND_DATA
		MVI C,03h
		CALL SEND_DATA
		RET


RST7_5ISR:	
		PUSH PSW
		PUSH B
		MVI C,01h	;clear lcd
		CALL SEND_CMD
		CALL DELAY_200MS
		MVI C,80h
		CALL SEND_CMD
		MVI B,08h
		LXI H,DATA_SETTINGS
AGAIN_1:	MOV C,M
		CALL SEND_DATA
		DCR B
		JZ NXT_2
		INX H
		JMP AGAIN_1
NXT_2:		MVI C,0C0h
		CALL SEND_CMD
		MVI B,08h
		LXI H,DATA_TIME
AGAIN_2:		MOV C,M
		CALL SEND_DATA
		DCR B
		JZ NXT_3
		INX H
		JMP AGAIN_2
NXT_3:		MVI C,94h
		CALL SEND_CMD
		MVI B,09h
		LXI H,DATA_ALAM
AGAIN_3:	MOV C,M
		CALL SEND_DATA
		DCR B
		JZ NXT_4
		INX H
		JMP AGAIN_3
NXT_4:		MVI C,0D4h
		CALL SEND_CMD
		MVI B,12h
		LXI H,DATA_ENTER
AGAIN_4:	MOV C,M
		CALL SEND_DATA
		DCR B
		JZ NXT_5
		INX H
		JMP AGAIN_4

NXT_5:		MVI C,0Fh
		CALL SEND_CMD	;JMP ENDSET
AGAIN:		CALL KEYPAD
		LXI H,PRESSED
		MOV A,M
		MOV B,A
		CPI 01h
		JNZ SECOND
		ADI 30h
		MOV C,A
		CALL SEND_DATA
		JMP FORWARD
SECOND: 	CPI 02h
		JNZ AGAIN
		ADI 30h
		MOV C,A
		CALL SEND_DATA
FORWARD:	MOV A,B
		CPI 01h
		JNZ SECOND_1
		CALL TIMESET
		JMP ENDSET
	
SECOND_1:		CALL ALAMSET
		

ENDSET:	MVI A,0DBh
		SIM
		MVI A,0CBh
		SIM
		MVI C,01h	;clear lcd
		CALL SEND_CMD
		POP B
		POP PSW
		POP B
		XRA A
		MOV B,A
		MOV C,A
		EI
		JMP MAININIT
		
TIMESET:	PUSH PSW
		PUSH B
		PUSH D
		MVI A,20h
		STA RTCA
		;MVI A,83h
		;STA RTCB
		MVI C,01h
		CALL SEND_CMD
		MVI C,80h
		CALL SEND_CMD
		MVI B,06h
		LXI H,DATA_HOUR
NXT_6:		MOV C,M
		CALL SEND_DATA
		DCR B
		JZ HOURIN
		INX H
		JMP NXT_6
HOURIN:	;	CALL DELAY_500MS
		CALL KEYPAD
		LXI H,PRESSED
		MOV A,M
		CPI 00h
		JNZ ON
		MVI C,30h
		CALL SEND_DATA
		JMP S1
ON:		CPI 01h
		JNZ TW
		MVI C,31h
		CALL SEND_DATA
		JMP S1
TW:		CPI 02h
		JNZ HOURIN
		MVI C,32h
		CALL SEND_DATA
S1:		RLC 
		RLC
		RLC
		RLC
		ANI 0F0h
		MOV E,A
LOOOP:		CALL KEYPAD
		LXI H,PRESSED
		MOV A,M
		CPI 0Fh
		JZ LOOOP
		ORA E
		MOV E,A
		ANI 0Fh
		ADI 30h
		MOV C,A
		CALL SEND_DATA
		MVI A,83h
		STA RTCB
		MOV A,E
		STA RTCHR	
		MVI A,03h
		STA RTCB	

MIN1:		MVI C,0C0h
		CALL SEND_CMD
		MVI B,08h
		LXI H,DATA_MIN
NXT_7:		MOV C,M
		CALL SEND_DATA
		DCR B
		JZ MININ
		INX H
		JMP NXT_7
MININ:		CALL KEYPAD
		LXI H,PRESSED
		MOV A,M
		CPI 00h
		JNZ ON1
		MVI C,30h
		CALL SEND_DATA
		JMP S2
ON1:		CPI 01h
		JNZ TW1
		MVI C,31h
		CALL SEND_DATA
		JMP S2
TW1:		CPI 02h
		JNZ TH1
		MVI C,32h
		CALL SEND_DATA
		JMP S2
TH1:		CPI 03h
		JNZ FO1
		MVI C,33h
		CALL SEND_DATA
		JMP S2
FO1:		CPI 04h
		JNZ FI1
		MVI C,34h
		CALL SEND_DATA
		JMP S2
FI1:		CPI 05h
		JNZ MININ
		MVI C,35h
		CALL SEND_DATA
S2:		RLC 
		RLC
		RLC
		RLC
		ANI 0F0h
		MOV E,A
LOOOP1:		CALL KEYPAD
		LXI H,PRESSED
		MOV A,M
		CPI 0Fh
		JZ LOOOP1
		ORA E
		MOV E,A
		ANI 0Fh
		ADI 30h
		MOV C,A
		CALL SEND_DATA
		MVI A,83h
		STA RTCB
		MOV A,E
		STA RTCMIN
		MVI A,00h
		STA RTCSEC
		MVI A,03h
		STA RTCB
		CALL DELAY_200MS
		;MVI A,03h
		;STA RTCB
		POP D
		POP B
		POP PSW
		RET

ALAMSET:	PUSH PSW
		PUSH B
		PUSH D
		MVI A,20h
		STA RTCA
		;MVI A,83h
		;STA RTCB
		MVI C,01h
		CALL SEND_CMD
		MVI C,80h
		CALL SEND_CMD
		MVI B,06h
		LXI H,DATA_HOUR
NXT_6_2:		MOV C,M
		CALL SEND_DATA
		DCR B
		JZ HOURIN_2
		INX H
		JMP NXT_6_2
HOURIN_2:	;CALL DELAY_500MS
		CALL KEYPAD
		LXI H,PRESSED
		MOV A,M
		CPI 00h
		JNZ ON_2
		MVI C,30h
		CALL SEND_DATA
		JMP S1_2
ON_2:		CPI 01h
		JNZ TW_2
		MVI C,31h
		CALL SEND_DATA
		JMP S1_2
TW_2:		CPI 02h
		JNZ HOURIN_2
		MVI C,32h
		CALL SEND_DATA
S1_2:		RLC 
		RLC
		RLC
		RLC
		ANI 0F0h
		MOV E,A
LOOOP_2:		CALL KEYPAD
		LXI H,PRESSED
		MOV A,M
		CPI 0Fh
		JZ LOOOP_2
		ORA E
		MOV E,A
		ANI 0Fh
		ADI 30h
		MOV C,A
		CALL SEND_DATA
		MVI A,83h
		STA RTCB
		MOV A,E
		STA RTCAHR	
		MVI A,03h
		STA RTCB

MIN1_2:		MVI C,0C0h
		CALL SEND_CMD
		MVI B,08h
		LXI H,DATA_MIN
NXT_7_2:		MOV C,M
		CALL SEND_DATA
		DCR B
		JZ MININ_2
		INX H
		JMP NXT_7_2
MININ_2:		CALL KEYPAD
		LXI H,PRESSED
		MOV A,M
		CPI 00h
		JNZ ON1_2
		MVI C,30h
		CALL SEND_DATA
		JMP S2_2
ON1_2:		CPI 01h
		JNZ TW1_2
		MVI C,31h
		CALL SEND_DATA
		JMP S2_2
TW1_2:		CPI 02h
		JNZ TH1_2
		MVI C,32h
		CALL SEND_DATA
		JMP S2_2
TH1_2:		CPI 03h
		JNZ FO1_2
		MVI C,33h
		CALL SEND_DATA
		JMP S2_2
FO1_2:		CPI 04h
		JNZ FI1_2
		MVI C,34h
		CALL SEND_DATA
		JMP S2_2
FI1_2:		CPI 05h
		JNZ MININ_2
		MVI C,35h
		CALL SEND_DATA
S2_2:		RLC 
		RLC
		RLC
		RLC
		ANI 0F0h
		MOV E,A
LOOOP1_2:		CALL KEYPAD
		LXI H,PRESSED
		MOV A,M
		CPI 0Fh
		JZ LOOOP1_2
		ORA E
		MOV E,A
		ANI 0Fh
		ADI 30h
		MOV C,A
		CALL SEND_DATA
		MVI A,83h
		STA RTCB
		MOV A,E
		STA RTCAMIN
		MVI A,00h
		STA RTCASEC
		MVI A,03h
		STA RTCB
		CALL DELAY_200MS
		;MVI A,03h
		;STA RTCB
		POP D
		POP B
		POP PSW
		RET

KEYPAD:	   PUSH PSW
	   PUSH H
;	CALL DELAY_200MS
COL1:	   IN PORTA
	   ANI 0F7h
	   OUT PORTA
	   CALL DELAY_2MS
	   IN PORTC
	   ANI 0Fh

PRES1:	   CPI 0Eh
	   JNZ PRES4
	   MVI A,01h
	   JMP ENDKEYPAD

PRES4:	   CPI 0Dh
	   JNZ PRES7
	   MVI A,04h
	   JMP ENDKEYPAD

PRES7:	   CPI 0Bh
	   JNZ PRESS10
	   MVI A,07h
	   JMP ENDKEYPAD

PRESS10:	CPI 07h
	   JNZ COL2
	   MVI A,0Ah
	   JMP ENDKEYPAD

COL2:	   IN PORTA
	   ORI 38h
	   ANI 0EFh
	   OUT PORTA
	   CALL DELAY_2MS
	   IN PORTC
	   ANI 0Fh

PRES2:	   CPI 0Eh
	   JNZ PRES5
	   MVI A,02h
	   JMP ENDKEYPAD

PRES5:	   CPI 0Dh
	   JNZ PRES8
	   MVI A,05h
	   JMP ENDKEYPAD

PRES8:	   CPI 0Bh
	   JNZ PRES0
	   MVI A,08h
	   JMP ENDKEYPAD

PRES0:	   CPI 07h
	   JNZ COL3
	   MVI A,00h
	   JMP ENDKEYPAD

COL3:	   IN PORTA
	   ORI 38h
	   ANI 0DFh
	   OUT PORTA
	   CALL DELAY_2MS
	   IN PORTC
	   ANI 0Fh

PRES3:	   CPI 0Eh
	   JNZ PRES6
	   MVI A,03h
	   JMP ENDKEYPAD

PRES6:	   CPI 0Dh
	   JNZ PRES9
	   MVI A,06h
	   JMP ENDKEYPAD

PRES9:	   CPI 0Bh
	   JNZ PRESS12
	   MVI A,09h
	   JMP ENDKEYPAD

PRESS12:	   CPI 07h
	   JNZ ENDKEYPAD
	   MVI A,0Ch
	   JMP ENDKEYPAD

ENDKEYPAD:	   CPI 0Fh
	JZ COL1
	LXI H,PRESSED
	   MOV M,A
	CALL DELAY_500MS
	   IN PORTA
	   ORI 38h
	   OUT PORTA
	   POP H
	   POP PSW
	   RET






PPINIT:	   MVI A,03h
	   OUT PPICSR
	   RET

LCD_INIT:	MVI C,38h	;8bit 2 line mode
	   CALL SEND_CMD
	   MVI C,01h	;clear lcd
	   CALL SEND_CMD
	   MVI C,0Ch	;display on, cursor off, blink off
	   CALL SEND_CMD
	   MVI C,06h	; entry mode
	   CALL SEND_CMD
	   RET

SEND_DATA:	   PUSH PSW
	   MOV A,C
	   OUT PORTB
	   IN PORTA
	   ORI LCDRS
	   OUT PORTA
	   ORI LCDEN
	   OUT PORTA
	   ANI 0FBh
	   OUT PORTA
	   CALL DELAY_2MS
	   POP PSW
	   RET

SEND_CMD:	   PUSH PSW	;C fro arg
	   MOV A,C	;COMMAND OUT
	   OUT PORTB
	   IN PORTA
	   ANI 0FDh	;for making rs 0
	   OUT PORTA	;sending rs before lcd_en
	   ORI LCDEN
	   OUT PORTA
	   ANI 0FBh
	   OUT PORTA
	   CALL DELAY_2MS
	   POP PSW
	   RET

HEXTOBCD:
	PUSH PSW
	MOV A,B
	ANI 0FH
	CPI 0AH
	JC SECONDNO
	ADI 06H
	;ANI 0FH
SECONDNO:
	MOV C,A
	MOV A,B
	ANI 0F0H
	CPI 0A0H
	JC ENDHEXTOBCD
	ADI 60H
	ANI 0F0H
ENDHEXTOBCD:
	ADD C
	MOV B,A
	POP PSW
	RET

DDSEND:	PUSH PSW  
	MOV A,B
	ANI 0F0H	;SEND DATA FROM A TO LCD
	RRC
	RRC
	RRC
	RRC
	ADI 30H
	MOV C,A
	CALL SEND_DATA
	MOV A,B
	ANI 0FH
	ADI 30H
	MOV C,A
	CALL SEND_DATA
	POP PSW
	RET

HEXTODECI:
		PUSH PSW
		PUSH D
		MVI C,00H
		MOV D,B
		MOV A,D
		RAR
		JNC SHFT1
		MOV A,C
		ADI 01H
		MOV C,A

SHFT1:	MOV A,D
		RAR
		RAR
		JNC SHFT2
		MOV A,C
		ADI 02H
		MOV C,A

SHFT2:	MOV A,D
		RAR
		RAR
		RAR
		JNC SHFT3
		MOV A,C
		ADI 04H
		MOV C,A

SHFT3:	MOV A,D
		RAR
		RAR
		RAR
		RAR
		JNC SHFT4
		MOV A,C
		ADI 08H
		MOV B,A
		CALL HEXTOBCD
		MOV C,B

SHFT4:	MOV A,D
		RAR
		RAR
		RAR
		RAR
		RAR
		JNC SHFT5
		MOV A,C
		ADI 16H
		MOV B,A
		CALL HEXTOBCD
		MOV C,B

SHFT5:	MOV A,D
		RAR
		RAR
		RAR
		RAR
		RAR
		RAR
		JNC ENDHEXTODECI
		MOV A,C
		ADI 32H
		MOV B,A
		CALL HEXTOBCD
		MOV C,B


ENDHEXTODECI:
		MOV B,C
		POP D
		POP PSW
		RET




DELAY_2MS:	
		PUSH PSW
		PUSH B
		LXI B,0103h

DELAY_2MSLOOP:	   
		DCX B
		MOV A,B
		ORA C
		JNZ DELAY_2MSLOOP
		POP B
		POP PSW
		RET
DELAY_200MS:
		PUSH PSW
		PUSH D
		LXI D,65B8h
DELAY_200MSLoop:
		DCX D
		MOV A,D
		ORA E
		JNZ DELAY_200MSLoop
		POP D
		POP PSW
		RET
	
DELAY_500MS:
		PUSH PSW
		PUSH D
		LXI D,0FE4Fh
DELAY_500MSLoop:
		DCX D
		MOV A,D
		ORA E
		JNZ DELAY_500MSLoop
		POP D  
		POP PSW
		RET
	
DELAY_1S:
	PUSH B
	PUSH D
	MVI B,1FH
DELAY_1SLOOP1:
	MVI C,4AH
DELAY_1SLOOP2:
	MVI D,60H
DELAY_1SLOOP3:
	DCR D
	JNZ DELAY_1SLOOP3
	DCR C
	JNZ DELAY_1SLOOP2
	DCR B
	JNZ DELAY_1SLOOP1
	POP D
	POP B
	RET

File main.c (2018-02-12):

#include <msp430.h> 
#include <inttypes.h>

#define CS BIT0
#define AS BIT1
#define WR BIT2
#define RD BIT3
#define RST BIT4
#define IRQ BIT5
#define RCLR BIT6
#define SQW BIT7
#define R_A 0x0A
#define R_B 0x0B
#define R_SEC 0x00
#define R_SEC_A 0x01
#define R_MIN 0x02
#define R_MIN_A 0x03
#define R_HR 0x04
#define R_HR_A 0x05
#define R_DAY_WEEK 0x06
#define R_DAY_MONTH 0x07
#define R_MO 0x08
#define R_YR 0x09

#define oscillator 0x20
#define rtc_rb 0x82

volatile int rdata;

void read(unsigned char raddress);
void write(unsigned char waddress, unsigned char wdata);

int main(void) {
    WDTCTL = WDTPW | WDTHOLD;	// Stop watchdog timer
	P2DIR &= 0x00;
	P2DIR |= CS + AS + WR + RD + RST + RCLR;
	P2OUT &= ~AS;
	P2OUT |= WR + RD + RST + RCLR;

	//write(R_B, 0x87);
	//write(R_SEC , 0x32);
	//write(R_MIN , 0x28);
	//write(R_HR , 0x14);
	//write(R_DAY_WEEK, 0x01);
	//write(R_DAY_MONTH, 0x0B);
	//write(R_MO, 0x02);
	//write(R_YR, 0x12);
	//write(R_YR , 18);
	//write(R_B , 0x07);

	while(1)
	{
		read(R_DAY_WEEK);
		read(R_DAY_MONTH);
		read(R_MO);
		read(R_YR);
		read(R_HR);
		read(R_MIN);
		read(R_SEC);
		read(R_B);
	}

}

void read(unsigned char raddress)
{
	P2OUT |= AS;
	P1DIR = 0xFF;
	P1OUT = raddress;
	__delay_cycles(1);
	P2OUT &= ~CS;
	P2OUT &= ~AS;
	__delay_cycles(1);
	P2OUT &= ~RD;
	__delay_cycles(1);
	P1DIR = 0x00;
	rdata = P1IN;
	__delay_cycles(1);
	P2OUT |= RD;
	P2OUT |= CS;
}

void write(unsigned char waddress, unsigned char wdata)
{
	P2OUT |= AS;
	P1DIR = 0xFF;
	P1OUT = waddress;
	__delay_cycles(1);
	P2OUT &= ~CS;
	P2OUT &= ~AS;
	__delay_cycles(1);
	P2OUT &= ~WR;
	P1OUT = wdata;
	__delay_cycles(1);
	P2OUT |= WR;
	P2OUT |= CS;

}

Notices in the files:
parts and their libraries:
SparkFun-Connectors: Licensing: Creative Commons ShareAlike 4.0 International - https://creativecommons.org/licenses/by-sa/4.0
